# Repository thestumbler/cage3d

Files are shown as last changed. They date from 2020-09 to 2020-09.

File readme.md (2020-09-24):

# A Novel 3D Printer Enclosure

## Overview

This is an enclosure, or cage, for my 3D printer which I designed with
an eye towards not burning down the house.  I make no claim that it
meets any real fire-proofing codes, but I tried to select material which
wasn't going to burst into flames easily.

The target 3D printer is an Ender 5 Pro.  I suspect the dimensions of
this enclosure would work with several different printers.  If you
simply want to change the size, that is easy to do in the OpenSCAD file.
If you want to change the design, as in different number and kinds of
doors, you'll need more than a passing familiarity with OpenSCAD.

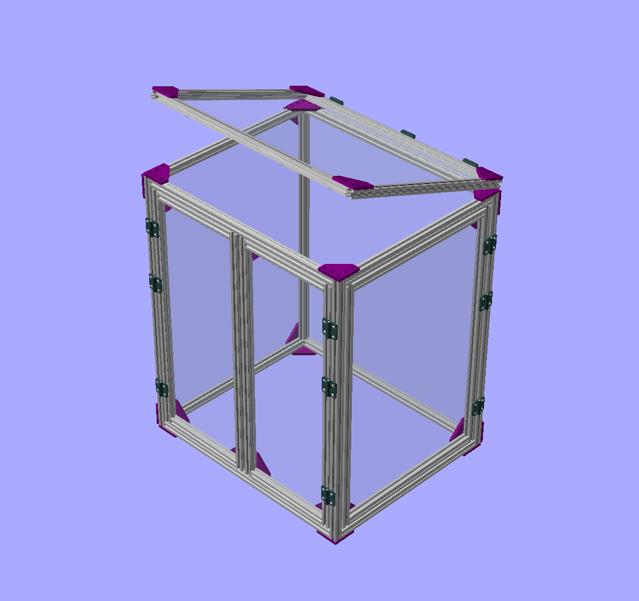
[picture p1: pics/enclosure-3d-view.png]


## Background

I've been curious for some time about 3D printers, but never took the
plunge until the virus hit.  Back in March, a friend of mine pointed 
out that he was making minuature people, cars, and buildings for his 
HO-gauge model railroad layout using a $300 printer from China.  
I knew the time had come.  His model was the Ender 3, but I splurged and
got the Ender 5 Pro.  

Shortly after receiving my new printer, another friend told me I needed
an enclosure, advice that I kept putting off until I realized he was
right.  After doing a little research, I wasn't really impressed with
any of the off-the-shelf solutions.  Having an enclosure that was not
flammable seemed to be desirable, but many of the popular ones weren't.  

I found a [discussion on reddit](https://www.reddit.com/r/3Dprinting/comments/6cn21j/has_anyone_built_a_fire_retardant_enclosure_for)
regarding fire-resistant boards which sounded promising. But I wasn't
readily able to find any cheaply here in South Korea.  I saw some people
were using plexiglass, but that's just plastic and would burn.
Then suddenly I realized that I could use tempered glass.
But I imagined the complex 3D pieces that would join panes of glass
together at the corners forming an enclosure, I became discouraged.  
Such a scheme would also need to accomodate doors, panels, mounting 
points for accessories, and I was about to abandon the idea.

Then I had another idea - use the same type of aluminum extrusions 
that comprised the 3D printer itself as frames for a glass enclosure.
This appeared to solve all my objections of custom joinery, and it
seemed to me, an electronics engineers, as a doable solution with
low-risk of failure.  But simple as it seemed, I was concerned about
building something like this without a metal working shop.

A bit of an aside, South Koreans are not really into the DIY scene.
Finding supplies that would be trivial to get in the US can be
challenging, if not impossible here.  In addition, without a workshop
here, extensive cutting, drilling, etc., is a non-starter.  To my
surprise, I was quickly able to find what I needed online, from
suppliers who did custom orders.  There are shops selling aluminum 2020
extrusions cut to custom lengths.  I also found a place that would cut
sheets of tempered glass to custom sizes, chamfers, and radii on
request.  With these newly-found resources at my fingertips, I was
encouraged to proceed.  

## See also:

* [Assembly instructions](assembly.md) guide on assembling the cage
* [Installation notes ](install.md) how to install the code, too basic
* [Gallery of pictures](gallery.md) an index into the pictures directory with some organization
* [Vendors used](vendors.md) list of vendors and links, useless unless you live in South Korea
* [Build log](build-log.md)
* [Design details](design.md)
* Datasheets directory (needs a few more datasheets)

## Design files:

* `cage.scad` OpenSCAD file
* `cage-bom.xlsx` BOM listing
  - `cage-bom-*.txt` intermediate bom text files generated by OpenSCAD
* `cage-panel.dwg` (also DXF and PDF files) drawing for basic panel

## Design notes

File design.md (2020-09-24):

# 3D Printer Enclosure Design Details

## Basic Construction

The basic building block of the enclosure, or cage, is a frame
made of standard 2020 aluminum profile extrusion.  The inside
grooves of these frames are used to hold a tempered glass panel.
The depth of the groove is 6mm, and I specified the glass panels 
to engage 5mm into the groove for a snug fit (see gasketing below).

One advantage of using 2020 extrusions is that accessories can easily be
mounted, such as a Raspi4 running Octoprint, LED light strips, etc.
My initial perception was that these profiles are reasonably cheap for
their functionality, but the key factor was they were easy for me obtain
in pre-cut lengths.

### Enclosure Size and Doors

The first step is to choose the size of the enclosure or cage.
Measuring my Ender 5 Pro printer, I decided on the following:

* 600 mm width, gives enough room for the filament spool
* 500 mm depth
* 700 mm height, should clear the filament feed tube

These dimensions are the outside dimensions in width and depth.
After wrapping up all the documentation, I realized the height was
actually 730 mm, slightly over one extusion width higher than the
"basic" dimension. This sneaked into the design as I was puzzling with
how to arrange all the doors, their frames, and the corners without
blocking the glass groove.  Somehow the top door ended up sitting atop
the whole cage, rather than recessed into the specified envelope.
In hindsight, this could probably be fixed, but at the time I was so
frustrated, I was just happy to get something that worked.

Three doors are included:

* Divided front doors to access the printing stage
* Side door to access to the filament reel and feeder
* Top door opens like a top-loader washing machine

## Joinery

I found several metal joints for 2D and 3D corners, some were really
cool cast aluminum joints.  But these usually interfered with the groove
for the glass.  But eventually I went with flat triangular corner plate.
I bought these, but they could be printed on your 3D printer.
User `Mighty Nozzle` has a library which includes these.

These plates use a lot of bolts, five per corner.  I'm not sure if they
are really necessary or not.  I erred on the side of caution, especially
after I calculated the weight of all this tempered glass.

## Hinges / Doors

Hinges were another concern, but I found some which were suitable sized
and spaced to make the doors. The ones I selected give a 5mm gap between
the frame and the doors.  I think that is a little large, but in the
beginning, I wasn't sure what kind of length tolerances I would get on
the extrusions.  I decided to keep a 5 mm door gap, and also to make all
dimensions a multiple of 5 mm.

Note, if you are using 3D printed corners, the gap could be an issue on
the top door.  In that case, the top door hinges would need to have a
larger gap, or else print those corners thinner. I found some hinges
that gave a 10 mm gap, which I think would be plenty.

## Meta

The design was visualized in OpenSCAD.  This is great for playing around
and experimenting with different options.  But it isn't so great for the
final documentation of the design.  The file becomes cluttered with all
kinds of visual aids and tests, like 

* XYZ axes
* grid lines (regular and isometric)
* overall dimension lines
* individual panel extrusion sizes (for assy help)
* animation to show exploded view, with lines
* poor-man's BOM generation `echo` statements

I tried comment it, but there will surely be questions, even from
myself.  Random remarks.

I wanted to make an isometric assembly drawing, and I will never take
this approach again.  What I did was draw isometric grid lines in
OpenSCAD, then export a PNG file, made the background transparent with
Gimp, and imported it into AutoCAD.  Whereupon I reconstructed the grids
on separate layers which I used as snap points to the Find Number
callouts.  I then replaced the AudoCAD image with another one without
isometric grids, and VOILA.  What a PITA.  It's time to take up bite the
bullet on Fusion 360.

Check out the script `mkbom.sh` which runs OpenSCAD from the command
line, and collects and sorts the output to create a really simple BOM.
The output isn't a perfect BOM, but it is a great starting point
containing the basic information needed on the "real" BOM.  Things like:

* X & Y dimensions of the finished panels
* length of individual extrusions
* X & Y dimensions of the glass panels
* perimeter of the glass panels (for gasket length)
* X + Y (sum) of glass panels (this is how the supplier prices them)
* weight of the extrusions and glass panels

## BOM and Rollups

TBD

## Tools

I tried to use open-source tools in the development of this project, but
failed, sort of.  OpenSCAD is open source, as is Gimp (see above).  I
used Excel for the BOM, but I could have used gnumeric or libreoffice.
The biggest break with open source tools is AutoCAD, or more precisely,
DraftSight.  I've been using them for years, when I lost my two ancient
AutoCAD license during a move.  Until recently, DraftSight was free.
But they have started charging an annual license fee, about $100 for the
entry level.  It is really hard to relearn 25 years of muscle memory of
the AutoCAD commands. And I so rarely use mechanical CAD tools, it's
tough to invest the time and/or money to learn a new tool.  I'm still
undecided on this one.  

The design files, however, should be usable in other open source tools.
The xlsx spreadsheets can be imported in other spreadsheet programs, and
I exported an ASCII DXF file from DraftSight.

## Metric

Because I live in South Korea, the overwhelming majority of material I
can get here is measured in Metric units. This design is dimensioned
accordingly.  Furthermore, fasteners are all metric threads.  I should
be a simple task to tweak the design to the equivalent Imperial units.
For example 

* M3 ~~ #4-40
* M3.5 ~~ #6-32 (oddball size?)
* M4 ~~ #8-32
* M5 ~~ #10-32 or #10-24

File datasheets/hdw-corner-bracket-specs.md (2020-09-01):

# Corner Bracket Specs

These limited specifications are take from this [AliExpress page](https://www.aliexpress.com/item/33007779262.html).

* Application: 
  - Build CNC routers
  - 3D printers
  - CNC laser cutters
  - CNC plasma cutters
  - robotics projects
  - 3D carvers
  - machine guards
  - workstations, etc.
* Compatible with: 
  - 2020 Series
  - Misumi Series
  - Openbuilds V-Slot
  - Openbuilds C-Beam
  - and other standard v-slot/L-slot 20mm aluminum extrusions
* For 2020 the size is 60mm x 60mm x 4mm
* Recommend to use M5 x10mm screw and M5 T nut
* Material: Aluminum
* Colour: Silver
* Aperture: M5
* Holes Spaced：20mm / 0.79 inch
* Thickness：4mm / 0.16 inch
* Dimensions: 60mm x 60mm /2.36 x 2.36 inch

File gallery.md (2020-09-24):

# Gallery of pictures

Just a markdown file to access the images, and a place to put comments
about the photos when appropriate.

## What Am I Making?

#### Enclosure (cage) for an Ender 5 Pro 3D printer
Enclosure (cage) for an Ender 5 Pro 3D printer

## First Test

Before jumping into the deep waters, I made a test panel first.
This is the smallest panel in the design, one of the front doors.

#### Test panel, front door
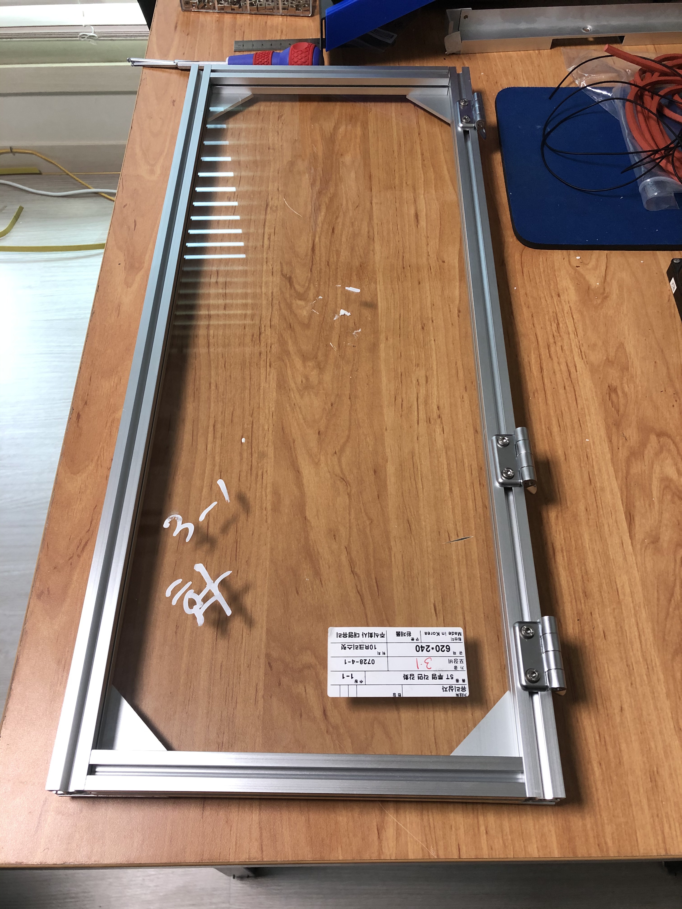
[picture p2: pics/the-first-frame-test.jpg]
Test panel, front door


## Detailed views

#### Frame corner detail
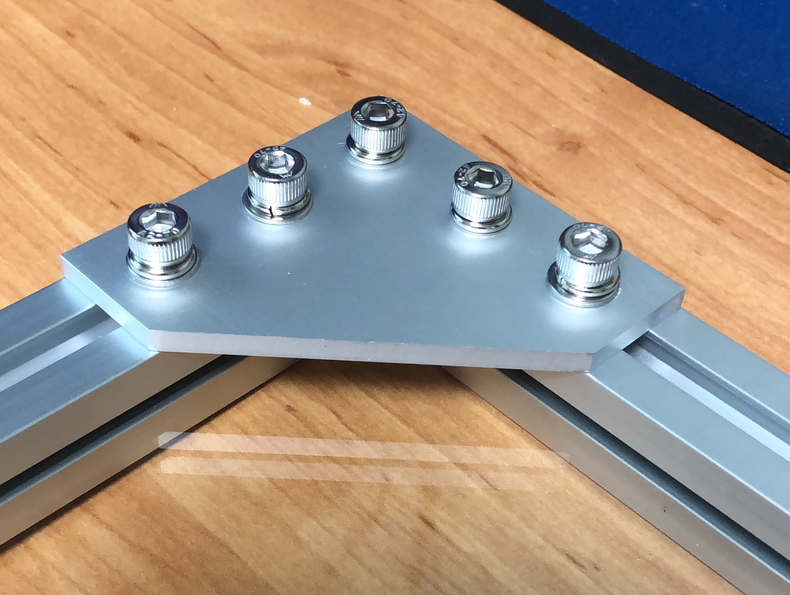
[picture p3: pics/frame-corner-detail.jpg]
Detail view of assembled frame corner


#### Frame hinge detail
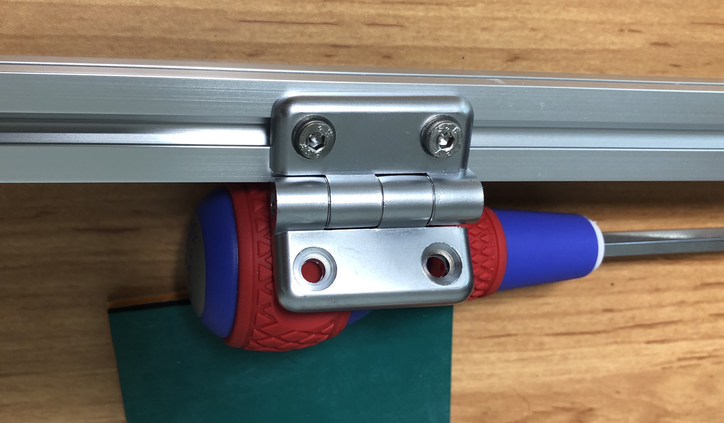
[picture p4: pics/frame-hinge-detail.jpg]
Detail view of hinge installation


## I Hate Rubber Gaskets

#### The pesky rubber gasket, my plan didn't go well
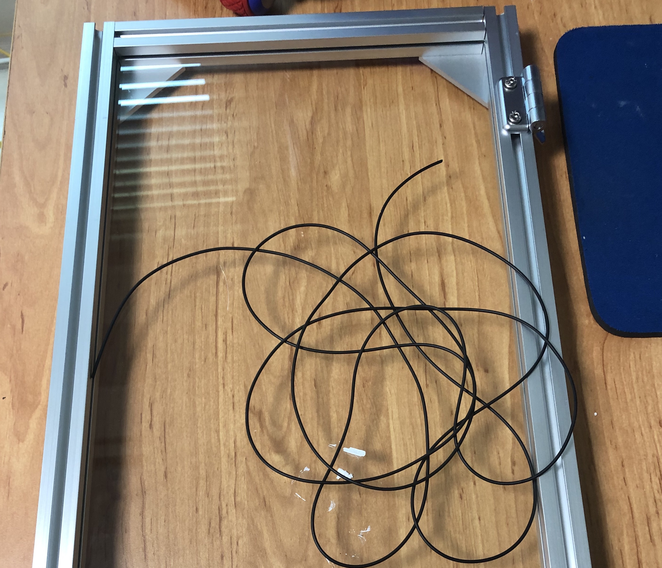
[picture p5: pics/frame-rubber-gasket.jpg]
The pesky rubber gasket


#### It looks good on paper
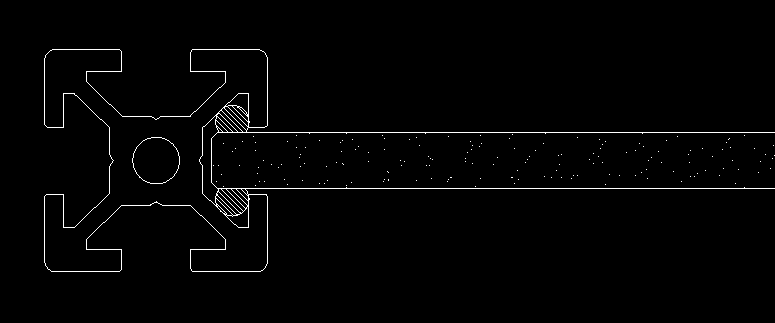
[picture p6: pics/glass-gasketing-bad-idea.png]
It looks good on paper


## Arriving Parts, Glass Panels

#### Glass panels arrived, surprisingly they didn't break
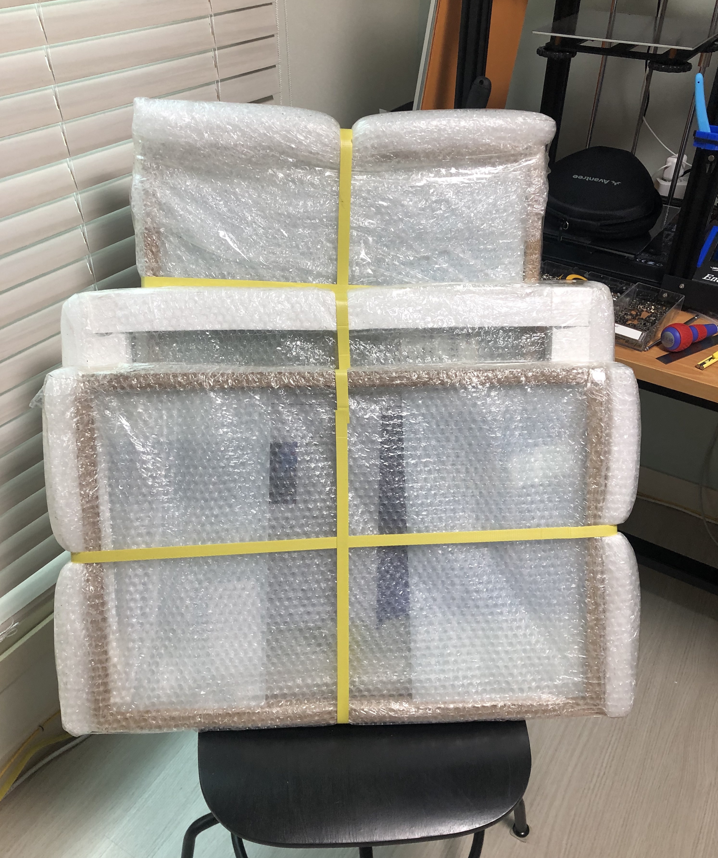
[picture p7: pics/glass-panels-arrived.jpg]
Glass panels arrived


#### Glass panels inspection, measure and check
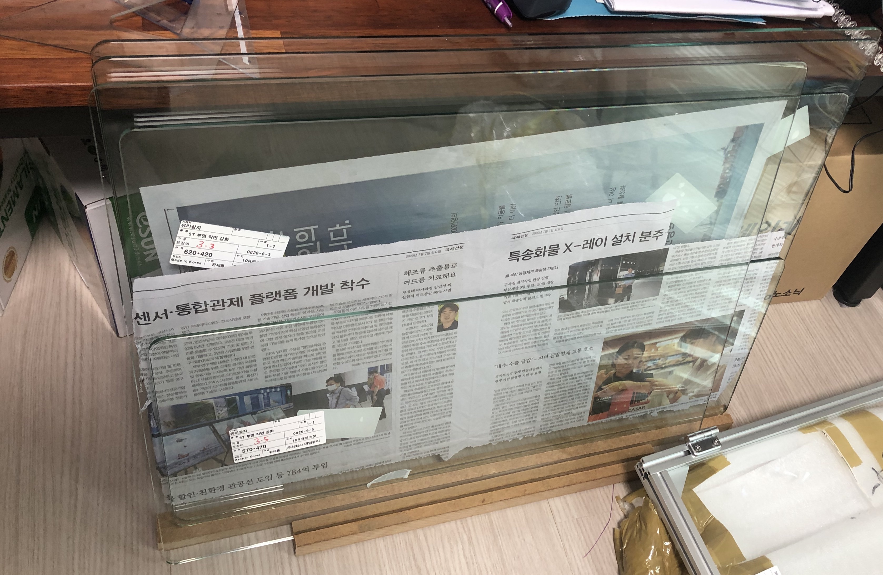
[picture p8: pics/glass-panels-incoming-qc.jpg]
Glass panels inspection


#### Separate our recycling required here in South Korea
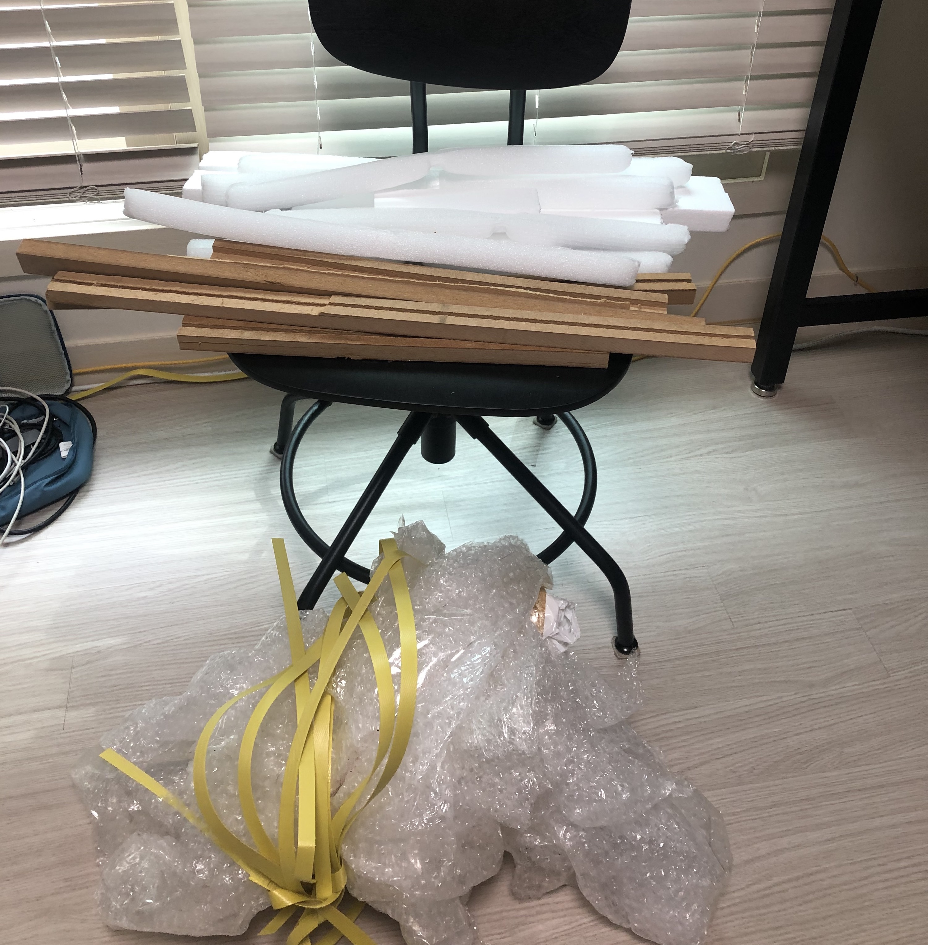
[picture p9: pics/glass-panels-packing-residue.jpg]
Glass panels packaging trash


## Arriving Parts, Extrusions

#### Aluminum profiles arrived
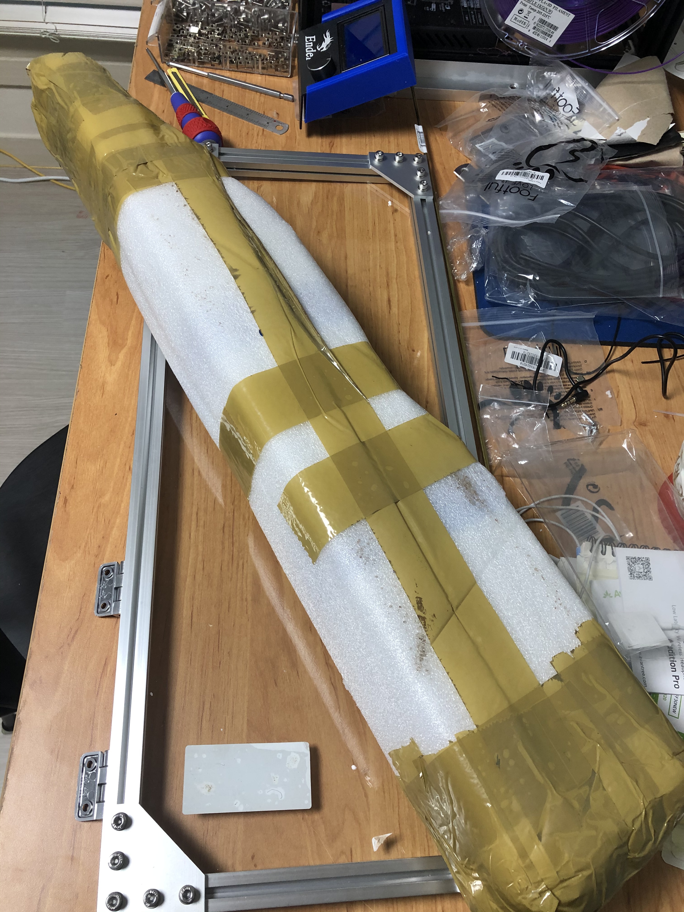
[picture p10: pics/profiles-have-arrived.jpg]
Aluminum profiles arrived


#### Aluminum profiles unpacked
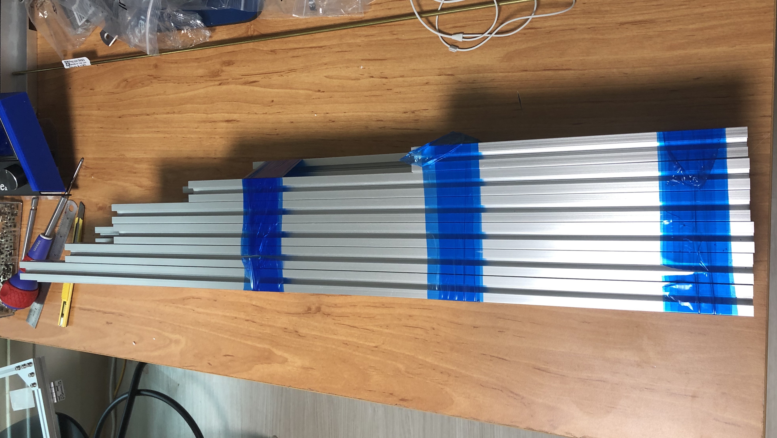
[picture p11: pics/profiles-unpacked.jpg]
Aluminum profiles unpacked


#### Aluminum profiles inspection.1 OOPS
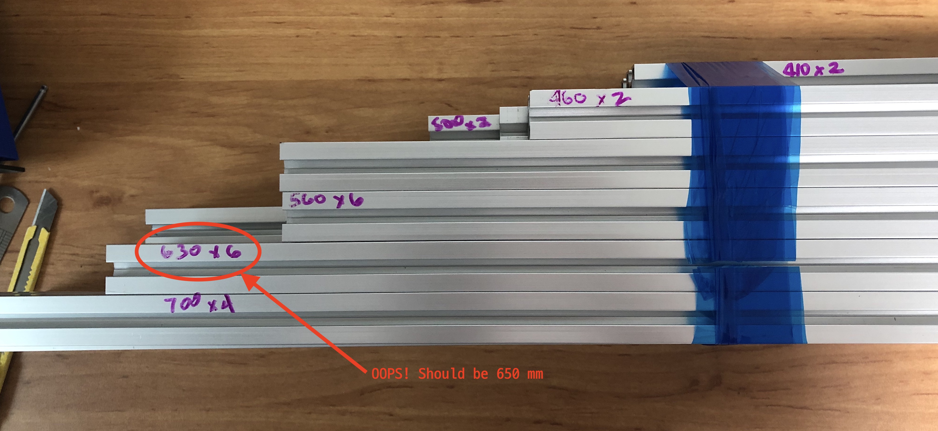
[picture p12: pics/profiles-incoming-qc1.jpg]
Aluminum profiles inspection.1 OOPS


#### Aluminum profiles inspection.2
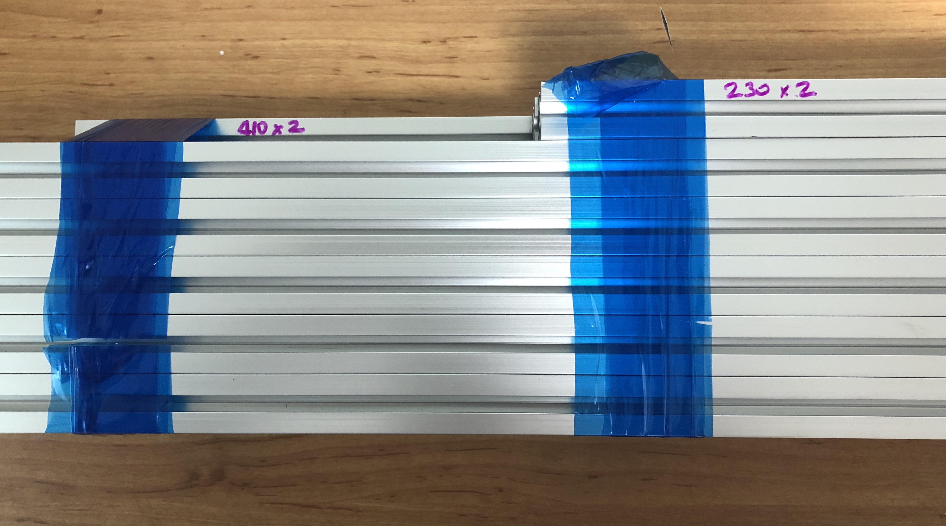
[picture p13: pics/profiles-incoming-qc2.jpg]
Aluminum profiles inspection.2


## Assembly Details

#### Completed Enclosure, Worms-eye view
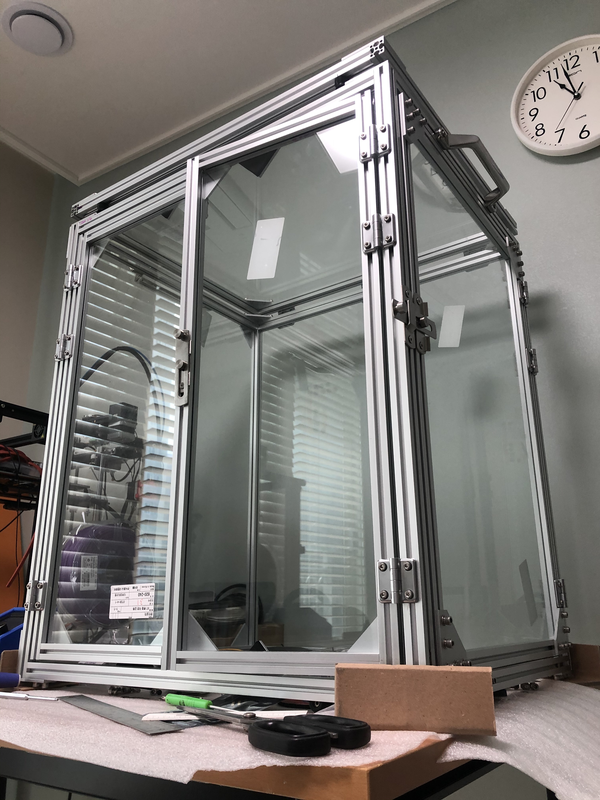
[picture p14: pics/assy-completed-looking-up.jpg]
Completed Enclosure, Worms-eye view


#### Almost There
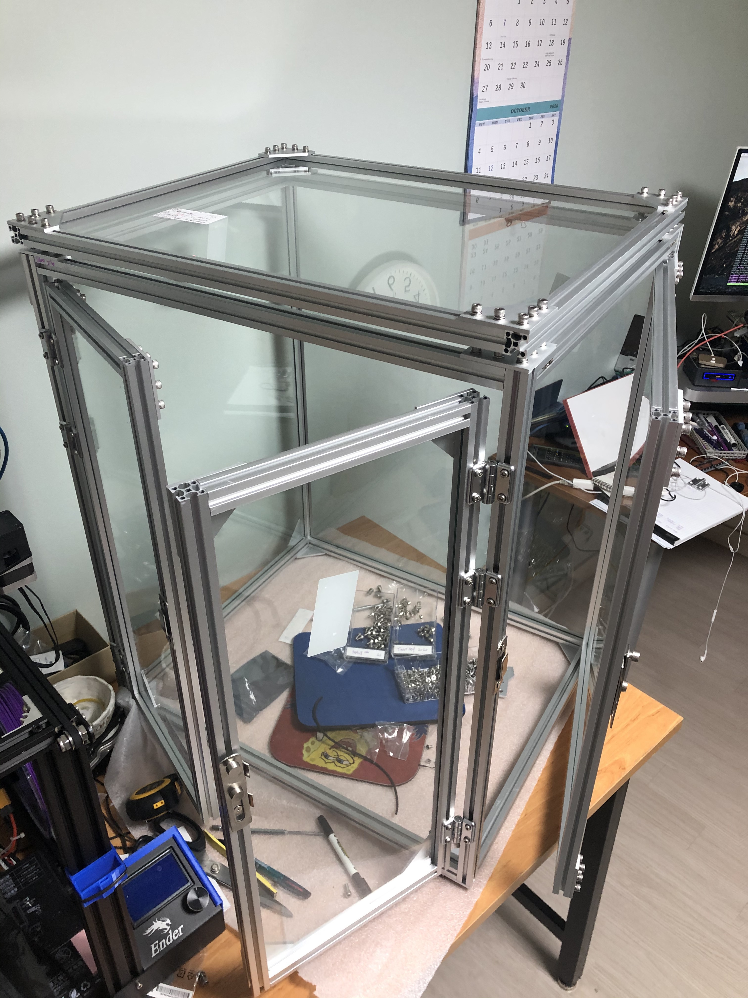
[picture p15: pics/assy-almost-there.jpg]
Almost There


#### Corner can slide
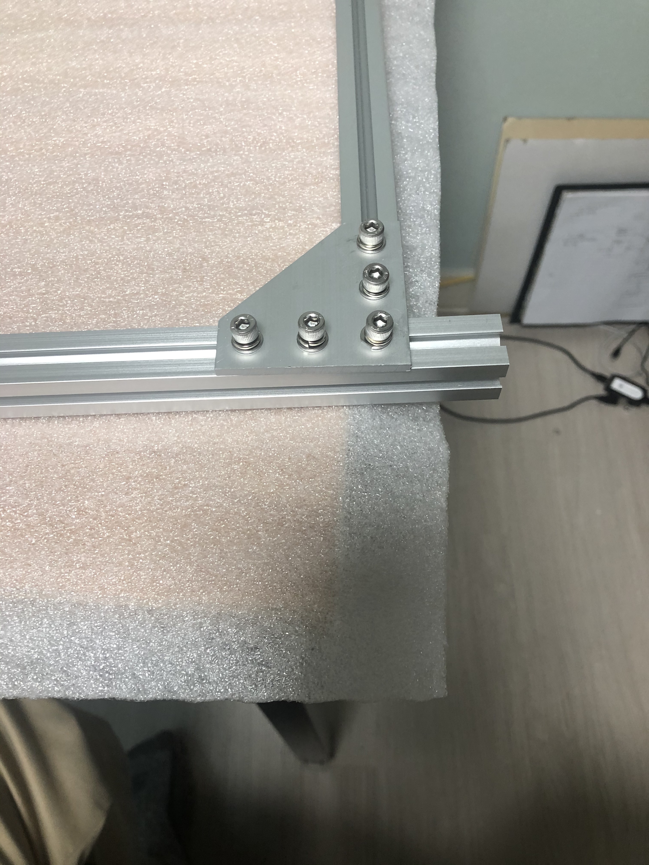
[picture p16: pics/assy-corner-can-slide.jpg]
Corner can slide


#### Completed corner
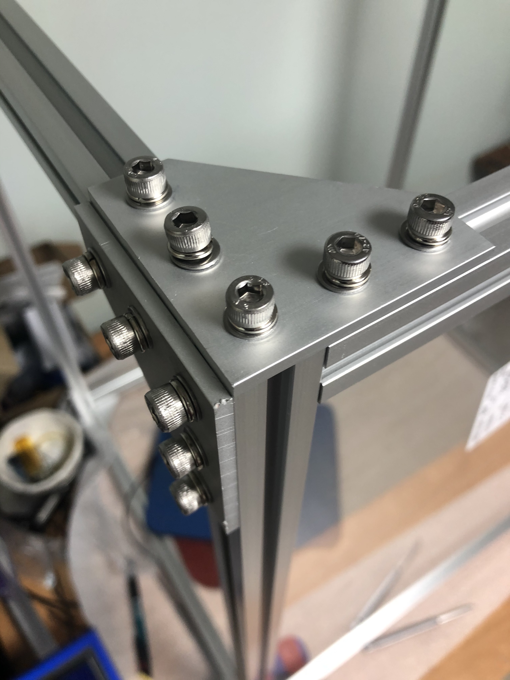
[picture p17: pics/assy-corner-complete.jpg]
Completed corner


#### Better not forget the square nuts
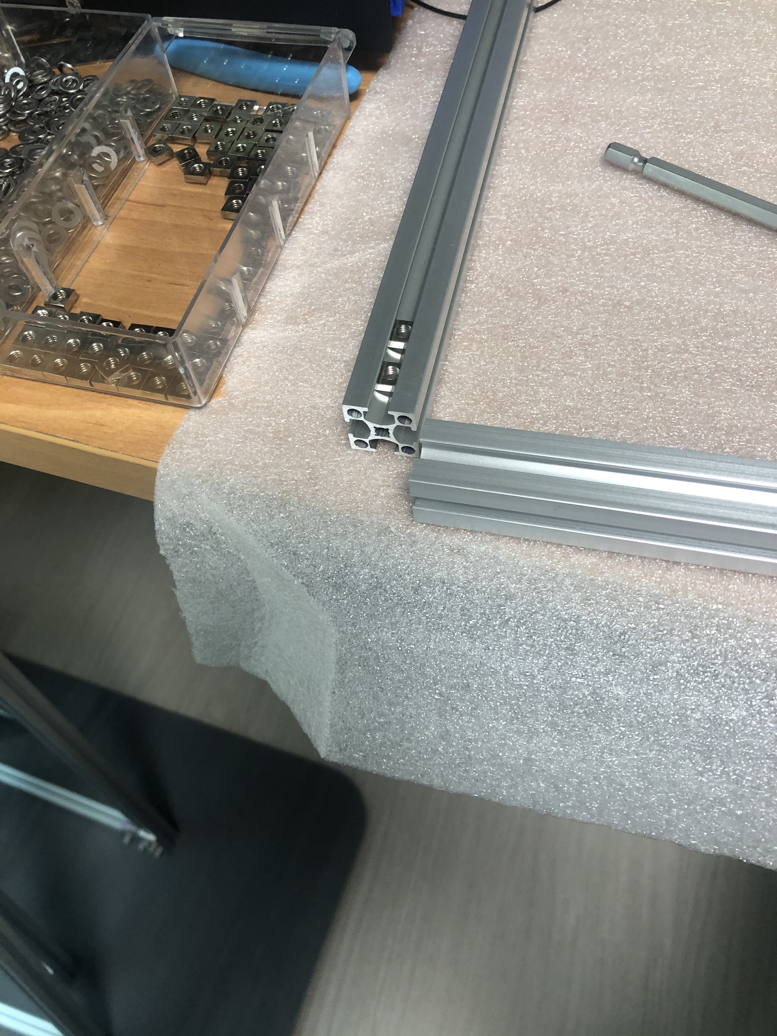
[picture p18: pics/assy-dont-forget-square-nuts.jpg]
Better not forget the square nuts


#### Too many square nuts
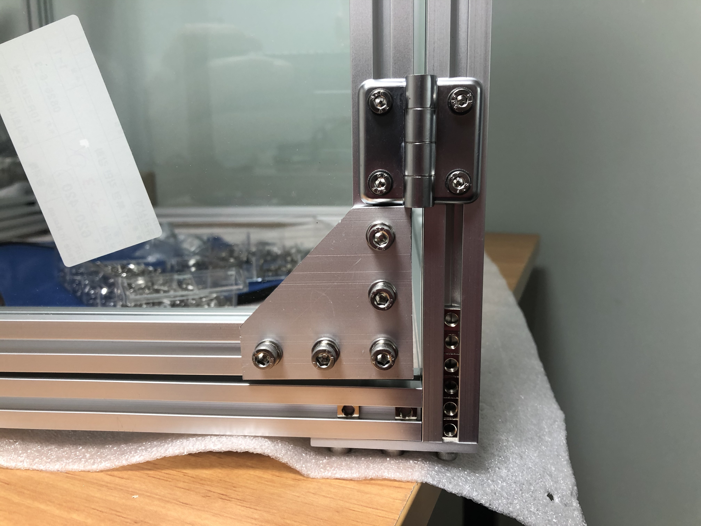
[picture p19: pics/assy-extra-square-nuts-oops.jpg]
Too many square nuts


#### Door latch detail
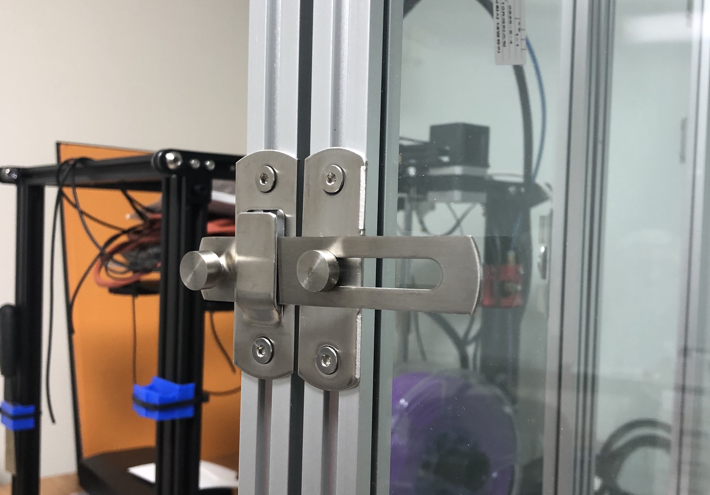
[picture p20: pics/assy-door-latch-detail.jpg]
Door latch detail


#### Door stop detail
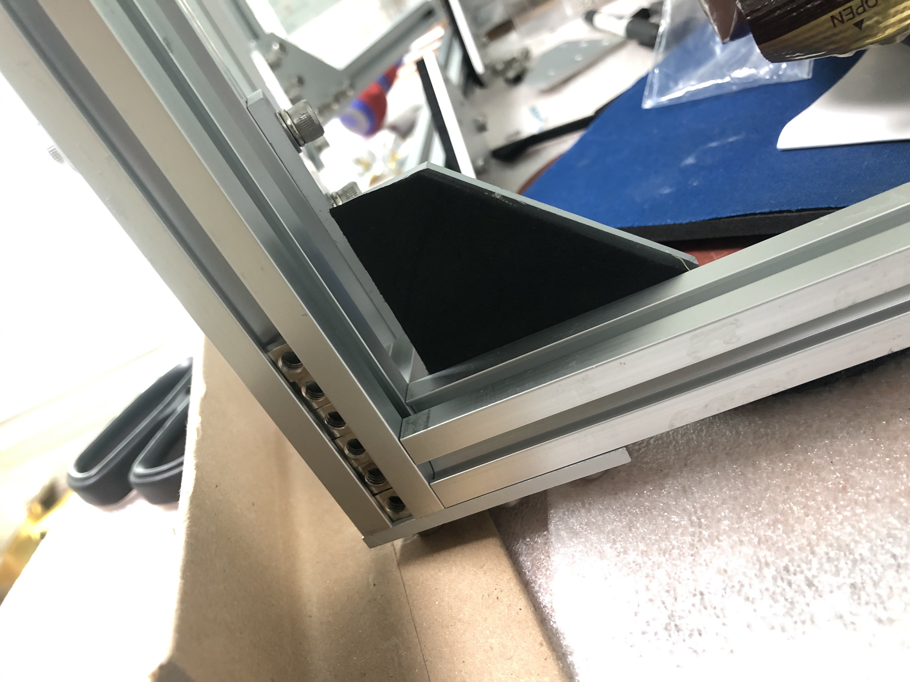
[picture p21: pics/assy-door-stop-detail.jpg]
Door stop detail


#### Example corner before installation
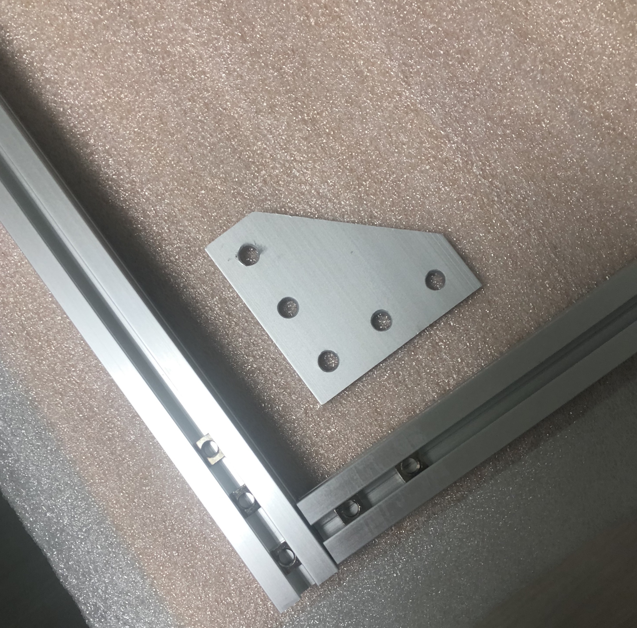
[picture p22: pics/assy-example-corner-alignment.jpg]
Example corner before installation


#### Front door stop detail
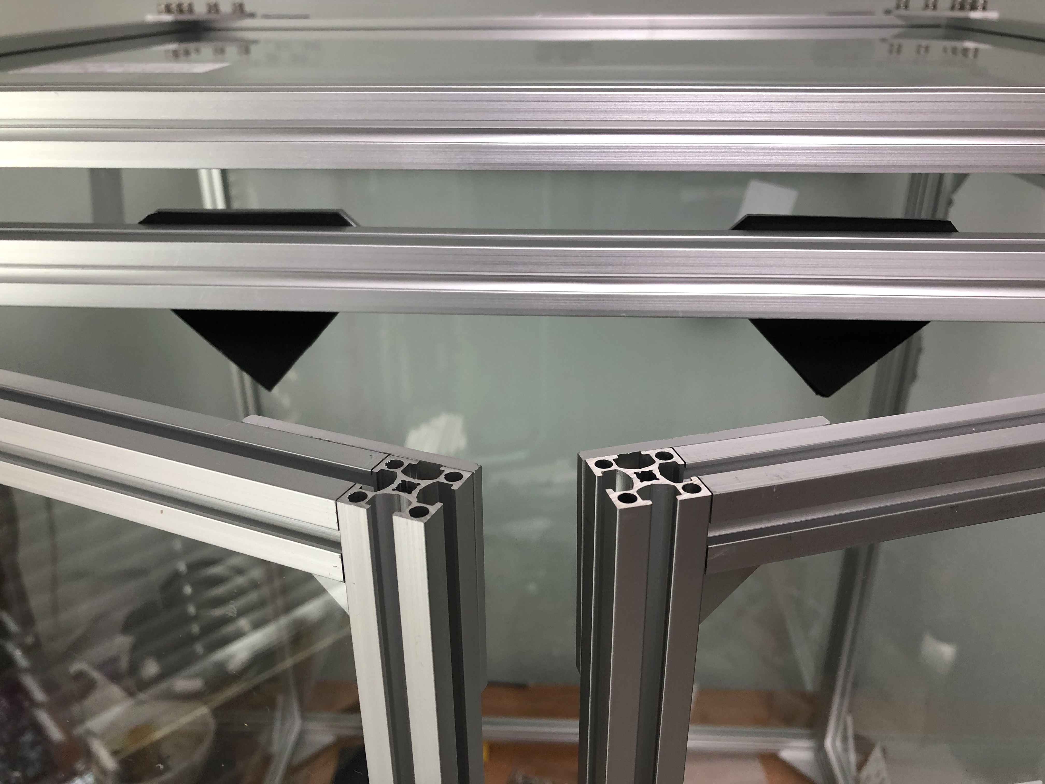
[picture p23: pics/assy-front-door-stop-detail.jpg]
Front door stop detail


#### Hinge detail
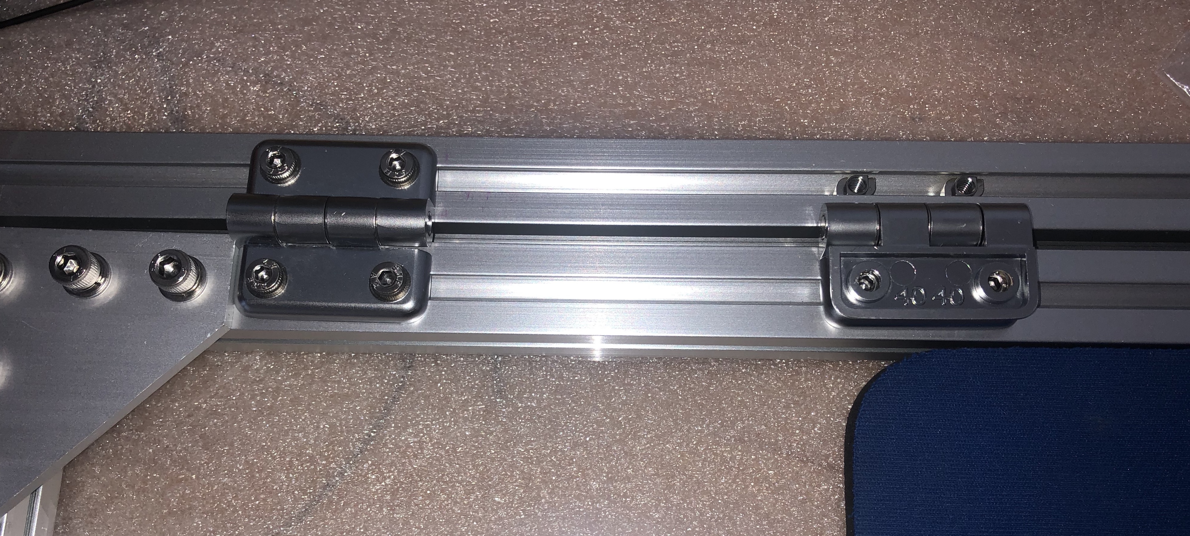
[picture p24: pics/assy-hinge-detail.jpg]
Hinge detail


#### Making door stops
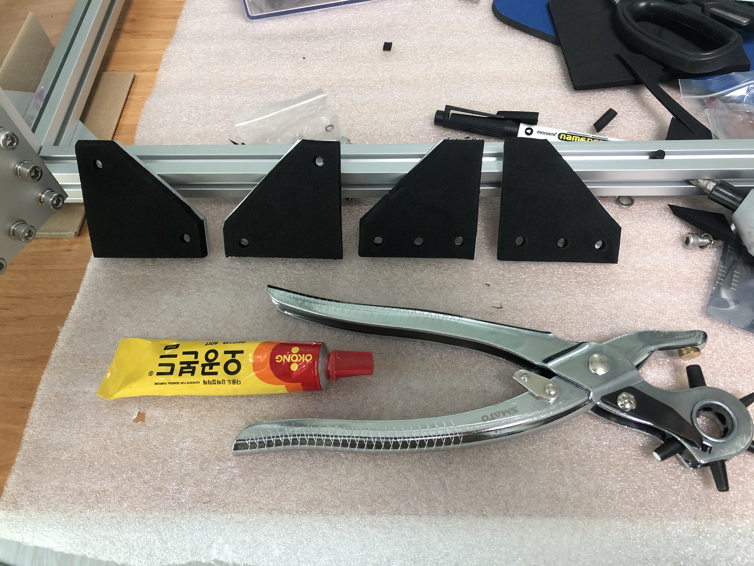
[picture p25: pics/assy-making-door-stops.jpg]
Making door stops


#### Rear hinge detail
Rear hinge detail

#### Tapping the end holes
Tapping the end holes

#### Tapping the end holes
Tapping the end holes

#### Tapping the end holes
Tapping the end holes

#### Cube assembled, time to tap the holes
Cube assembled, time to tap the holes

#### Tee-nut, right and wrong
Tee-nut, right and wrong

#### Top door bumpers, left
Top door bumpers, left

#### Top door bumpers, right
Top door bumpers, right

## Candidate cast aluminum corners

I passed on these despite them being really cool

#### cast corner 2D, internal style
cast corner 2D, internal style

#### cast corner 2D, external style
cast corner 2D, external style

#### cast corner 3D, internal style
cast corner 3D, internal style

## Misc stuff

#### Assembly hardwware
Assembly hardwware

#### Hex nut dimensions
Hex nut dimensions

#### Glass panels assembled
Glass panels assembled

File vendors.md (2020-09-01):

# Vendors used in this project

This list will be almost useless unless you live in South Korea.
I primarily made it for my own reference, but the links might give 
someone hints for locating similar items in their region.

* Aluminum 2020 extrusions
  - http://global.gmarket.co.kr/item?goodsCode=1688992222
* Tempered Glass panels
  - http://global.gmarket.co.kr/item?goodsCode=1344564398
* Aluminum Corners:
  - https://www.aliexpress.com/item/33007779262.html
* Hinges, HC4040 matte finish, cast
  - http://global.gmarket.co.kr/item?goodsCode=802764159
* Rubber seal candidates:
  * 5mm square, pink silicon foam, 25-30 shore A
    - http://global.gmarket.co.kr/item?goodsCode=1344564398
  * Black NBR rubber, various diameters, 70 shore A
    - http://global.gmarket.co.kr/item?goodsCode=1461701921
* Latches
  - https://www.coupang.com/vp/products/295612249
* Hardware (machine screws, bolts, washers, etc.)
  - Samdi Mall
  - Youngwon Tool

### CH77 Special Rubber Co.

```
CH77 Special Rubber Co.
http://ch77-7.com
197 Gurojungang-ro, 
Guro-dong, Guro-gu, Seoul
tel: 02-6232-8700

씨에이치특수고무
```

### Myeongga Hardware Co.

```
Myeongga Hardware Co.
24, Sinchon-ro, Dongnam-gu, 
Cheonan-si, Chungcheongnam-do
web: http://www.mg9000.com
web: http://www.mgjs.co.kr

충청남도 천안시 신방동 784-1
```

### Dae Myoung Glass Company

```
Dae Myoung Glass Company
web: http://dm-glass.co.kr
```

### Dongwon Tech / 09-Play

```
Dongwon Tech / 09-Play
Bldg 16, Suite 113, Siheung Distribution Center
97, Siheung-daero, Geumcheon-gu, Seoul
tel:02-6264-8992
email: dwcnt@naver.com
web: http://www.09play.co.kr

동원테크
서울특별시 금천구 시흥대로 97
시흥유통상가) 16동 113호
```

### Youngwon Tool

```
Youngwon Tool
Korea Iso Co Building
152, Sandong-ro, Eumbong-myeon
Asan-si, Chungcheongnam-do
tel: 041-557-1516
email: yw6987@daum.net
web: http://01mall.co.kr

충청남도 아산시 음봉면 산동로 152
```

### Samdi Mall

```
Samdi Mall
Dongyang Bldg, 2nd floor
301 Bucheon-ro, 
Bucheon-si, Gyeonggi-do
tel: 032-674-7037
email: samdimall@gmail.com
web: http://www.samdimall.com

경기도 부천시 부천로 301 동양빌딩 2층
```

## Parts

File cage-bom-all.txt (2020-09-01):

BOM	panel.side.left	500	700	460	700
BOM	ex2020	460	0.1748
BOM	ex2020	460	0.1748
BOM	ex2020	700	0.266
BOM	ex2020	700	0.266
BOM	corner	5
BOM	corner	5
BOM	corner	5
BOM	corner	5
BOM	glass.side.left	470	670	0.3149	2280	3.93625
BOM	panel.side.right.noglass	500	700	460	700
BOM	ex2020	460	0.1748
BOM	ex2020	460	0.1748
BOM	ex2020	700	0.266
BOM	ex2020	700	0.266
BOM	ex2020.standalone	560	0.2128
BOM	ex2020.standalone	560	0.2128
BOM	corner.standalone	5
BOM	corner.standalone	5
BOM	corner.standalone	5
BOM	corner.standalone	5
BOM	ex2020.standalone	560	0.2128
BOM	ex2020.standalone	560	0.2128
BOM	corner.standalone	5
BOM	corner.standalone	5
BOM	corner.standalone	5
BOM	corner.standalone	5
BOM	glass.back.standalone	570	670	0.3819	2480	4.77375
BOM	corner.standalone	5
BOM	corner.standalone	5
BOM	corner.standalone	5
BOM	corner.standalone	5
BOM	panel.side.door	450	650	410	650
BOM	ex2020	410	0.1558
BOM	ex2020	410	0.1558
BOM	ex2020	650	0.247
BOM	ex2020	650	0.247
BOM	corner	5
BOM	corner	5
BOM	corner	5
BOM	corner	5
BOM	hinge	4
BOM	hinge	4
BOM	hinge	4
BOM	glass.side.door	420	620	0.2604	2080	3.255
BOM	panel.front.door.left	270	650	230	650
BOM	ex2020	230	0.0874
BOM	ex2020	230	0.0874
BOM	ex2020	650	0.247
BOM	ex2020	650	0.247
BOM	corner	5
BOM	corner	5
BOM	corner	5
BOM	corner	5
BOM	hinge	4
BOM	hinge	4
BOM	hinge	4
BOM	glass.front.door.left	240	620	0.1488	1720	1.86
BOM	panel.front.door.right	270	650	230	650
BOM	ex2020	230	0.0874
BOM	ex2020	230	0.0874
BOM	ex2020	650	0.247
BOM	ex2020	650	0.247
BOM	corner	5
BOM	corner	5
BOM	corner	5
BOM	corner	5
BOM	hinge	4
BOM	hinge	4
BOM	hinge	4
BOM	glass.front.door.right	240	620	0.1488	1720	1.86
BOM	panel.top.door	600	500	560	500
BOM	ex2020	560	0.2128
BOM	ex2020	560	0.2128
BOM	ex2020	500	0.19
BOM	ex2020	500	0.19
BOM	corner	5
BOM	corner	5
BOM	corner	5
BOM	corner	5
BOM	glass.top.door	570	470	0.2679	2080	3.34875
BOM	hinge	4
BOM	hinge	4
BOM	hinge	4

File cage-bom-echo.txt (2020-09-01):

ECHO: [0, 0.125, 0.25, 0.375, 0.5, 0.625, 0.75, 0.875, 1]
ECHO: "BOM	panel.side.left	500	700	460	700"
ECHO: "BOM	ex2020	460	0.1748"
ECHO: "BOM	ex2020	460	0.1748"
ECHO: "BOM	ex2020	700	0.266"
ECHO: "BOM	ex2020	700	0.266"
ECHO: "BOM	corner	5"
ECHO: "BOM	corner	5"
ECHO: "BOM	corner	5"
ECHO: "BOM	corner	5"
ECHO: "BOM	glass.side.left	470	670	0.3149	2280	3.93625"
ECHO: "BOM	panel.side.right.noglass	500	700	460	700"
ECHO: "BOM	ex2020	460	0.1748"
ECHO: "BOM	ex2020	460	0.1748"
ECHO: "BOM	ex2020	700	0.266"
ECHO: "BOM	ex2020	700	0.266"
ECHO: "BOM	ex2020.standalone	560	0.2128"
ECHO: "BOM	ex2020.standalone	560	0.2128"
ECHO: "BOM	corner.standalone	5"
ECHO: "BOM	corner.standalone	5"
ECHO: "BOM	corner.standalone	5"
ECHO: "BOM	corner.standalone	5"
ECHO: "BOM	ex2020.standalone	560	0.2128"
ECHO: "BOM	ex2020.standalone	560	0.2128"
ECHO: "BOM	corner.standalone	5"
ECHO: "BOM	corner.standalone	5"
ECHO: "BOM	corner.standalone	5"
ECHO: "BOM	corner.standalone	5"
ECHO: "BOM	glass.back.standalone	570	670	0.3819	2480	4.77375"
ECHO: "BOM	corner.standalone	5"
ECHO: "BOM	corner.standalone	5"
ECHO: "BOM	corner.standalone	5"
ECHO: "BOM	corner.standalone	5"
ECHO: "BOM	panel.side.door	450	650	410	650"
ECHO: "BOM	ex2020	410	0.1558"
ECHO: "BOM	ex2020	410	0.1558"
ECHO: "BOM	ex2020	650	0.247"
ECHO: "BOM	ex2020	650	0.247"
ECHO: "BOM	corner	5"
ECHO: "BOM	corner	5"
ECHO: "BOM	corner	5"
ECHO: "BOM	corner	5"
ECHO: "BOM	hinge	4"
ECHO: "BOM	hinge	4"
ECHO: "BOM	hinge	4"
ECHO: "BOM	glass.side.door	420	620	0.2604	2080	3.255"
ECHO: "BOM	panel.front.door.left	270	650	230	650"
ECHO: "BOM	ex2020	230	0.0874"
ECHO: "BOM	ex2020	230	0.0874"
ECHO: "BOM	ex2020	650	0.247"
ECHO: "BOM	ex2020	650	0.247"
ECHO: "BOM	corner	5"
ECHO: "BOM	corner	5"
ECHO: "BOM	corner	5"
ECHO: "BOM	corner	5"
ECHO: "BOM	hinge	4"
ECHO: "BOM	hinge	4"
ECHO: "BOM	hinge	4"
ECHO: "BOM	glass.front.door.left	240	620	0.1488	1720	1.86"
ECHO: "BOM	panel.front.door.right	270	650	230	650"
ECHO: "BOM	ex2020	230	0.0874"
ECHO: "BOM	ex2020	230	0.0874"
ECHO: "BOM	ex2020	650	0.247"
ECHO: "BOM	ex2020	650	0.247"
ECHO: "BOM	corner	5"
ECHO: "BOM	corner	5"
ECHO: "BOM	corner	5"
ECHO: "BOM	corner	5"
ECHO: "BOM	hinge	4"
ECHO: "BOM	hinge	4"
ECHO: "BOM	hinge	4"
ECHO: "BOM	glass.front.door.right	240	620	0.1488	1720	1.86"
ECHO: "BOM	panel.top.door	600	500	560	500"
ECHO: "BOM	ex2020	560	0.2128"
ECHO: "BOM	ex2020	560	0.2128"
ECHO: "BOM	ex2020	500	0.19"
ECHO: "BOM	ex2020	500	0.19"
ECHO: "BOM	corner	5"
ECHO: "BOM	corner	5"
ECHO: "BOM	corner	5"
ECHO: "BOM	corner	5"
ECHO: "BOM	glass.top.door	570	470	0.2679	2080	3.34875"
ECHO: "BOM	hinge	4"
ECHO: "BOM	hinge	4"
ECHO: "BOM	hinge	4"

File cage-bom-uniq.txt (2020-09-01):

  20 BOM	corner	5
  12 BOM	corner.standalone	5
   4 BOM	ex2020	230	0.0874
   2 BOM	ex2020	410	0.1558
   4 BOM	ex2020	460	0.1748
   2 BOM	ex2020	500	0.19
   2 BOM	ex2020	560	0.2128
   6 BOM	ex2020	650	0.247
   4 BOM	ex2020	700	0.266
   4 BOM	ex2020.standalone	560	0.2128
   1 BOM	glass.back.standalone	570	670	0.3819	2480	4.77375
   1 BOM	glass.front.door.left	240	620	0.1488	1720	1.86
   1 BOM	glass.front.door.right	240	620	0.1488	1720	1.86
   1 BOM	glass.side.door	420	620	0.2604	2080	3.255
   1 BOM	glass.side.left	470	670	0.3149	2280	3.93625
   1 BOM	glass.top.door	570	470	0.2679	2080	3.34875
  12 BOM	hinge	4
   1 BOM	panel.front.door.left	270	650	230	650
   1 BOM	panel.front.door.right	270	650	230	650
   1 BOM	panel.side.door	450	650	410	650
   1 BOM	panel.side.left	500	700	460	700
   1 BOM	panel.side.right.noglass	500	700	460	700
   1 BOM	panel.top.door	600	500	560	500

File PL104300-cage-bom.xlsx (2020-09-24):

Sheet: bom
TITLE |  | ENDER 5 PRO ENCLOSURE ASSY
DWG TYPE |  | ASSY, TOP LEVEL PARTS LIST
PART NO |  | PL104300
DESIGNER |  | CHRIS LOTT
COMPANY |  | THE STUMBLER
LOCATION |  | SACHEON, SOUTH KOREA
PAGE |  | 1 of 3
TOP-LEVEL ASSEMBLY PARTS LIST
F/N | Qty | Reference | COMM | Manufacturer | PartNo | Description | Remarks | Vendor | StockingNo
101 | 1 | FG.L | ASY | STUMBLER | 104320-700-500-FG | Panel, Frame w/Glass, 700 x 500 mm
102 | 1 | FX.R | ASY | STUMBLER | 104320-700-500-F | Panel, Frame no Glass, 700 x 500 mm
103 | 1 | PS.K | ASY | STUMBLER | 104320-600-700-G | Panel, Pseudo, Glass w/no Frame
104 | 1 | PS.T, PS.B | ASY | STUMBLER | 104320-000-600 | Panel, Pseudo, Frame
151 | 2 | DR.FL, DR.FR | ASY | STUMBLER | 104320-650-270-FG | Panel, Frame w/Glass, 650 x 270 mm
152 | 1 | DR.T | ASY | STUMBLER | 104320-500-600-FG | Panel, Frame w/Glass, 500 x 600 mm
153 | 1 | DR.R | ASY | STUMBLER | 104320-650-450-FG | Panel, Frame w/Glass, 650 x 450 mm
232 | 12 |  | HDW |  |  | Hinges |  | MYEONGGA
225 | 48 |  | HDW |  |  | Screw, MS, SHCS, SS, M4 x |  | SAMDI
226 | 48 |  | HDW |  |  | Nut, 2020 Tee-slot, SS, M4 |  | SAMDI
 | REFERENCE DESIGNATOR KEY:
 | FG | Frame Panel w/Glass
 | FX | Frame Panel w/Glass
 | PS | Pseudo panel
 | DR | Door
 | Suffix:
 | L | Left
 | R | Right
 | T | Top
 | B | Bottom
 | F | Front
 | K | bacK

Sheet: roll-down
TITLE |  | ENDER 5 PRO ENCLOSURE ASSY
DWG TYPE |  | ASSY, TOP LEVEL PARTS LIST
PART NO |  | PL104300
DESIGNER |  | CHRIS LOTT
COMPANY |  | THE STUMBLER
LOCATION |  | SACHEON, SOUTH KOREA
PAGE |  | 2 of 3
EXPLODED PARTS LIST, SORTED BY SUB-ASSEMBLY
F/N | Used-On | Qty | Reference | COMM | Description
207 | 101.1 | 2 | FG.L | MECH | Extrusion, 2020 AL, 700 mm
203 | 101.2 | 2 | FG.L | MECH | Extrusion, 2020 AL, 460 mm
215 | 101.3 | 1 | FG.L | CER | Glass, tempered, 670 x 470 x 5mm, R=10mm
211 | 101.4 | 2.28 | FG.L | RUB | Gasket Seal for 670 x 470 glass panel
231 | 101.5 | 4 | FG.L | HDW | Corners
222 | 101.6 | 20 | FG.L | HDW | Screw, MS, SHCS, SS, M5 x
223 | 101.7 | 20 | FG.L | HDW | Washer, Flat, SS, M5
224 | 101.8 | 20 | FG.L | HDW | Washer, Locking, Split-ring, SS, M5
221 | 101.9 | 20 | FG.L | HDW | Nut, Square, SS, 8x8x3mm, M5
207 | 102.1 | 2 | FX.R | MECH | Extrusion, 2020 AL, 700 mm
203 | 102.2 | 2 | FX.R | MECH | Extrusion, 2020 AL, 460 mm
231 | 102.3 | 4 | FX.R | HDW | Corners
222 | 102.4 | 20 | FX.R | HDW | Screw, MS, SHCS, SS, M5 x
223 | 102.5 | 20 | FX.R | HDW | Washer, Flat, SS, M5
224 | 102.6 | 20 | FX.R | HDW | Washer, Locking, Split-ring, SS, M5
221 | 102.7 | 20 | FX.R | HDW | Nut, Square, SS, 8x8x3mm, M5
215 | 103.1 | 1 | PS.K | CER | Glass, tempered, 670 x 570 x 5mm, R=10mm
211 | 103.2 | 2.48 | PS.K | RUB | Gasket Seal for 670 x 570 glass panel
231 | 103.3 | 4 | PS.K | HDW | Corners
222 | 103.4 | 20 | PS.K | HDW | Screw, MS, SHCS, SS, M5 x
223 | 103.5 | 20 | PS.K | HDW | Washer, Flat, SS, M5
224 | 103.6 | 20 | PS.K | HDW | Washer, Locking, Split-ring, SS, M5
221 | 103.7 | 20 | PS.K | HDW | Nut, Square, SS, 8x8x3mm, M5
205 | 104.11 | 2 | PS.T | MECH | Extrusion, 2020 AL, 560 mm
231 | 104.12 | 4 | PS.T | HDW | Corners
222 | 104.13 | 20 | PS.T | HDW | Screw, MS, SHCS, SS, M5 x
223 | 104.14 | 20 | PS.T | HDW | Washer, Flat, SS, M5
224 | 104.15 | 20 | PS.T | HDW | Washer, Locking, Split-ring, SS, M5
221 | 104.16 | 20 | PS.T | HDW | Nut, Square, SS, 8x8x3mm, M5
205 | 104.21 | 2 | PS.B | MECH | Extrusion, 2020 AL, 560 mm
231 | 104.22 | 4 | PS.B | HDW | Corners
222 | 104.23 | 20 | PS.B | HDW | Screw, MS, SHCS, SS, M5 x
223 | 104.24 | 20 | PS.B | HDW | Washer, Flat, SS, M5
224 | 104.25 | 20 | PS.B | HDW | Washer, Locking, Split-ring, SS, M5
221 | 104.26 | 20 | PS.B | HDW | Nut, Square, SS, 8x8x3mm, M5
206 | 151.11 | 2 | DR.FL | MECH | Extrusion, 2020 AL, 650 mm
201 | 151.12 | 2 | DR.FL | MECH | Extrusion, 2020 AL, 230 mm
213 | 151.13 | 1 | DR.FL | CER | Glass, tempered, 620 x 240 x 5mm, R=10mm
211 | 151.14 | 1.72 | DR.FL | RUB | Gasket Seal for 620 x 240 glass panel
231 | 151.15 | 4 | DR.FL | HDW | Corners
222 | 151.16 | 20 | DR.FL | HDW | Screw, MS, SHCS, SS, M5 x
223 | 151.17 | 20 | DR.FL | HDW | Washer, Flat, SS, M5
224 | 151.18 | 20 | DR.FL | HDW | Washer, Locking, Split-ring, SS, M5
221 | 151.19 | 20 | DR.FL | HDW | Nut, Square, SS, 8x8x3mm, M5
206 | 151.21 | 2 | DR.FR | MECH | Extrusion, 2020 AL, 650 mm
201 | 151.22 | 2 | DR.FR | MECH | Extrusion, 2020 AL, 230 mm
213 | 151.23 | 1 | DR.FR | CER | Glass, tempered, 620 x 240 x 5mm, R=10mm
211 | 151.24 | 1.72 | DR.FR | RUB | Gasket Seal for 620 x 240 glass panel
231 | 151.25 | 4 | DR.FR | HDW | Corners
222 | 151.26 | 20 | DR.FR | HDW | Screw, MS, SHCS, SS, M5 x
223 | 151.27 | 20 | DR.FR | HDW | Washer, Flat, SS, M5
224 | 151.28 | 20 | DR.FR | HDW | Washer, Locking, Split-ring, SS, M5
221 | 151.29 | 20 | DR.FR | HDW | Nut, Square, SS, 8x8x3mm, M5
204 | 152.1 | 2 | DR.T | MECH | Extrusion, 2020 AL, 500 mm
205 | 152.2 | 2 | DR.T | MECH | Extrusion, 2020 AL, 560 mm
212 | 152.3 | 1 | DR.T | CER | Glass, tempered, 570 x 470 x 5mm, R=10mm
211 | 152.4 | 2.08 | DR.T | RUB | Gasket Seal for 570 x 470 glass panel
231 | 152.5 | 4 | DR.T | HDW | Corners
222 | 152.6 | 20 | DR.T | HDW | Screw, MS, SHCS, SS, M5 x
223 | 152.7 | 20 | DR.T | HDW | Washer, Flat, SS, M5
224 | 152.8 | 20 | DR.T | HDW | Washer, Locking, Split-ring, SS, M5
221 | 152.9 | 20 | DR.T | HDW | Nut, Square, SS, 8x8x3mm, M5
206 | 153.1 | 2 | DR.R | MECH | Extrusion, 2020 AL, 650 mm
202 | 153.2 | 2 | DR.R | MECH | Extrusion, 2020 AL, 410 mm
214 | 153.3 | 1 | DR.R | CER | Glass, tempered, 620 x 420 x 5mm, R=10mm
211 | 153.4 | 2.08 | DR.R | RUB | Gasket Seal for 620 x 420 glass panel
231 | 153.5 | 4 | DR.R | HDW | Corners
222 | 153.6 | 20 | DR.R | HDW | Screw, MS, SHCS, SS, M5 x
223 | 153.7 | 20 | DR.R | HDW | Washer, Flat, SS, M5
224 | 153.8 | 20 | DR.R | HDW | Washer, Locking, Split-ring, SS, M5
221 | 153.9 | 20 | DR.R | HDW | Nut, Square, SS, 8x8x3mm, M5
232 | 0 | 12 |  | HDW | Hinges
225 | 0 | 48 |  | HDW | Screw, MS, SHCS, SS, M4 x
226 | 0 | 48 |  | HDW | Nut, 2020 Tee-slot, SS, M4

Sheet: roll-up
TITLE |  | ENDER 5 PRO ENCLOSURE ASSY
DWG TYPE |  | ASSY, TOP LEVEL PARTS LIST
PART NO |  | PL104300
DESIGNER |  | CHRIS LOTT
COMPANY |  | THE STUMBLER
LOCATION |  | SACHEON, SOUTH KOREA
PAGE |  | 3 of 3
ROLLED-UP / COMBINED PARTS LIST, TO PURCHASE |  |  |  |  |  |  |  |  |  |  | 25.639 |  |  | $227.46
Item | Qty | Reference | COMM | Manufacturer | PartNo | Description | xParam | yParam | zParam | Dens | Weight
201 | 4 | DR.FL, DR.FR | MECH | DONGWON TECH | AL2020x230 | Extrusion, 2020 AL, 230 mm | 230 |  |  | 0.38 | 0.350 | 300 | $1.28 | $5.12
202 | 2 | DR.R | MECH | DONGWON TECH | AL2020x410 | Extrusion, 2020 AL, 410 mm | 410 |  |  | 0.38 | 0.312 | 500 | $2.06 | $4.12
203 | 4 | FG.L, FX.R | MECH | DONGWON TECH | AL2020x460 | Extrusion, 2020 AL, 460 mm | 460 |  |  | 0.38 | 0.699 | 500 | $2.06 | $8.24
204 | 2 | DR.T | MECH | DONGWON TECH | AL2020x500 | Extrusion, 2020 AL, 500 mm | 500 |  |  | 0.38 | 0.380 | 500 | $2.06 | $4.12
205 | 6 | PS.T, PS.B, DR.T | MECH | DONGWON TECH | AL2020x560 | Extrusion, 2020 AL, 560 mm | 560 |  |  | 0.38 | 1.277 | 600 | $2.56 | $15.36
206 | 6 | DR.FL, DR.FR, DR.R | MECH | DONGWON TECH | AL2020x650 | Extrusion, 2020 AL, 650 mm | 650 |  |  | 0.38 | 1.482 | 700 | $3.00 | $18.00
207 | 4 | FG.L, FX.R | MECH | DONGWON TECH | AL2020x700 | Extrusion, 2020 AL, 700 mm | 700 |  |  | 0.38 | 1.064 | 700 | $3.00 | $12.00
211 | 12.36 | All glass panels | RUB | CH77 RUBBER |  | Gasket Seal 3mm dia, for glass panel (meter) |  |  |  |  |  | 15 | $0.30 | $4.50
212 | 1 | DR.T | CER | DAE MYEONG |  | Glass, tempered, 570 x 470 x 5mm, R=10mm | 570 | 470 | 5 | 2500 | 3.349 | 1040 | $10.00 | $10.00
213 | 2 | DR.FL, DR.FR | CER | DAE MYEONG |  | Glass, tempered, 620 x 240 x 5mm, R=10mm | 620 | 240 | 5 | 2500 | 3.720 | 860 | $8.00 | $16.00
214 | 1 | DR.R | CER | DAE MYEONG |  | Glass, tempered, 620 x 420 x 5mm, R=10mm | 620 | 420 | 5 | 2500 | 3.255 | 1040 | $10.00 | $10.00
215 | 1 | FG.L | CER | DAE MYEONG |  | Glass, tempered, 670 x 470 x 5mm, R=10mm | 670 | 470 | 5 | 2500 | 3.936 | 1140 | $11.00 | $11.00
216 | 1 | PS.K | CER | DAE MYEONG |  | Glass, tempered, 670 x 570 x 5mm, R=10mm | 670 | 570 | 5 | 2500 | 4.774 | 1240 | $11.00 | $11.00
221 | 180 | All corners | HDW | SAMDI |  | Nut, Square, Steel, 8x8x3mm, M5 |  |  |  |  |  | 200 | $0.10 | $20.00
222 | 180 | All corners | HDW | YOUNGWON TOOL |  | Screw, MS, SHCS, SS, M5 x 12mm |  |  |  |  |  | 200 | $0.06 | $12.00
223 | 180 | All corners | HDW | YOUNGWON TOOL |  | Washer, Flat, SS, M5 |  |  |  |  |  | 200 | $0.03 | $6.00
224 | 180 | All corners | HDW | YOUNGWON TOOL |  | Washer, Locking, Split-ring, SS, M5 |  |  |  |  |  | 200 | $0.02 | $4.00
225 | 48 | All corners | HDW | YOUNGWON TOOL |  | Screw, MS, SHCS, SS, M4 x 8mm |  |  |  |  |  | 50 | $0.04 | $2.00
226 | 48 | All hinges | HDW | DONGWON TECH |  | Nut, 2020 Tee-slot, SS, M4 |  |  |  |  |  | 50 | $0.18 | $9.00
231 | 36 | All hinges | HDW | ALI-GROUNDHOG | 2020-CORNER-AL | Corners | 10.725 | 10.725 | 10.725 | 2.7 | 1.042 | 36 | $1.25 | $45.00
232 | 12 | DR.FL, DR.FR, DR.R, DR.T | HDW | MYEONGGA | HC4040-CAST | Hinges |  |  |  |  |  | 12 | $4.35 | $52.20
 |  |  |  |  |  |  |  |  |  |  |  | 2480
 |  |  |  |  |  |  |  |  |  |  |  | 1720
 |  |  |  |  |  |  |  |  |  |  |  | 1720
 |  |  |  |  |  |  |  |  |  |  |  | 2080
 |  |  |  |  |  |  |  |  |  |  |  | 2280
 |  |  |  |  |  |  |  |  |  |  |  | 2080

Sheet: SMT SIZES
ENGLISH | METRIC | SIZE (INCHES) |  | SIZE (MILLIMETERS)
01005 | 0402 | 0.016 | 0.008 | 0.40 | 0.20
0201 | 0603 | 0.024 | 0.012 | 0.60 | 0.30
0402 | 1005 | 0.040 | 0.020 | 1.00 | 0.50
0603 | 1608 | 0.063 | 0.031 | 1.60 | 0.80
0805 | 2013 | 0.080 | 0.050 | 2.00 | 1.25
1008 | 2520 | 0.100 | 0.080 | 2.50 | 2.00
1206 | 3216 | 0.126 | 0.063 | 3.20 | 1.60
1210 | 3225 | 0.126 | 0.100 | 3.20 | 2.50
1808 | 4516 | 0.177 | 0.063 | 4.50 | 1.60
1812 | 4532 | 0.180 | 0.120 | 4.50 | 3.20
2010 | 5025 | 0.200 | 0.100 | 5.00 | 2.50
2512 | 6431 | 0.250 | 0.120 | 6.35 | 3.05

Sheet: COMMODITY CODES
IC | Integrated
MCD | Integrated Circuit, Digital
MCA | Integrated Circuit, Analog (or combination)
SEM | Semiconductors (transistor, diodes, LED, etc.)
OSC | Crystals and Oscillators
CAP | Capacitors
RES | Resistors
IND | Inductors, Transformers, Ferrites
FUS | Fuses and circuit breakers
CON | Connectors, plugs, jacks, headers, etc.
SWI | Switches, Pushbuttons
ASY | Sub-Assemblies
HDW | Hardware, screws, feet, brackets, etc.
MSC | Miscellaneous
NUL | Nothing (e.g., fiducial, test point, etc.)
MECH | Mechanical structure
CER | Glass and ceramic
RUB | Rubber, Neoprene, etc.

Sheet: THREADS
Metric | Basic | Coarse | Approx | Matching | Basic | UNC | UNF
Thread | Dia (in) | Pitch | TPI | UTS Size | Dia (in) | TPI | TPI
M2 | 0.079 | 0.4 | 63 | #2 | 0.086 | 56 | 64
M3 | 0.118 | 0.5 | 50 | #4 | 0.112 | 40 | 48
M3.5 (*) | 0.138 | 0.6 | 42 | #6 | 0.138 | 32 | 40
M4 | 0.157 | 0.7 | 36 | #8 | 0.164 | 32 | 36
M5 | 0.197 | 0.8 | 32 | #10 | 0.190 | 24 | 32
M6 | 0.236 | 1.0 | 25 | 1/4 | 0.250 | 20 | 28
UTS-Unified Thread Standard (Used in USA and Canada)
UNC - Unified National Coarse
UNF - Unified National Fine
TPI - Threads per Inch
(*) non-standard size?

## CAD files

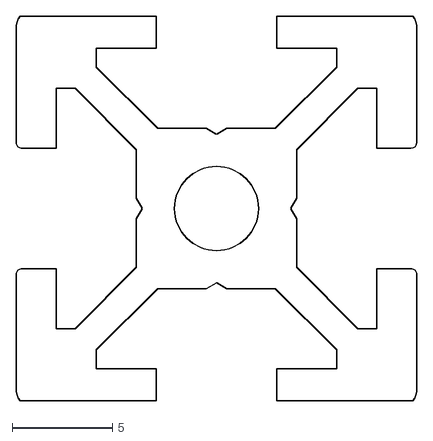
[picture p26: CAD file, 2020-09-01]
uses/2020.dxf
20.0 x 19.2

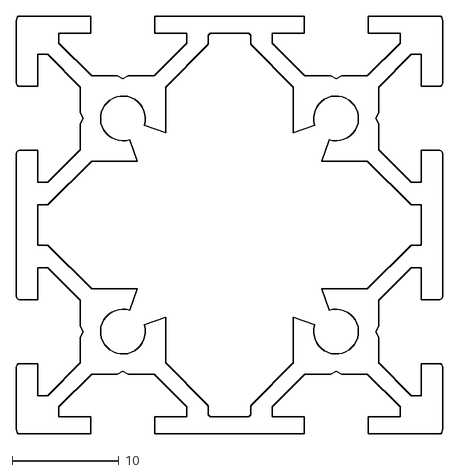
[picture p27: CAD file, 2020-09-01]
uses/4040.dxf
40.0 x 39.2

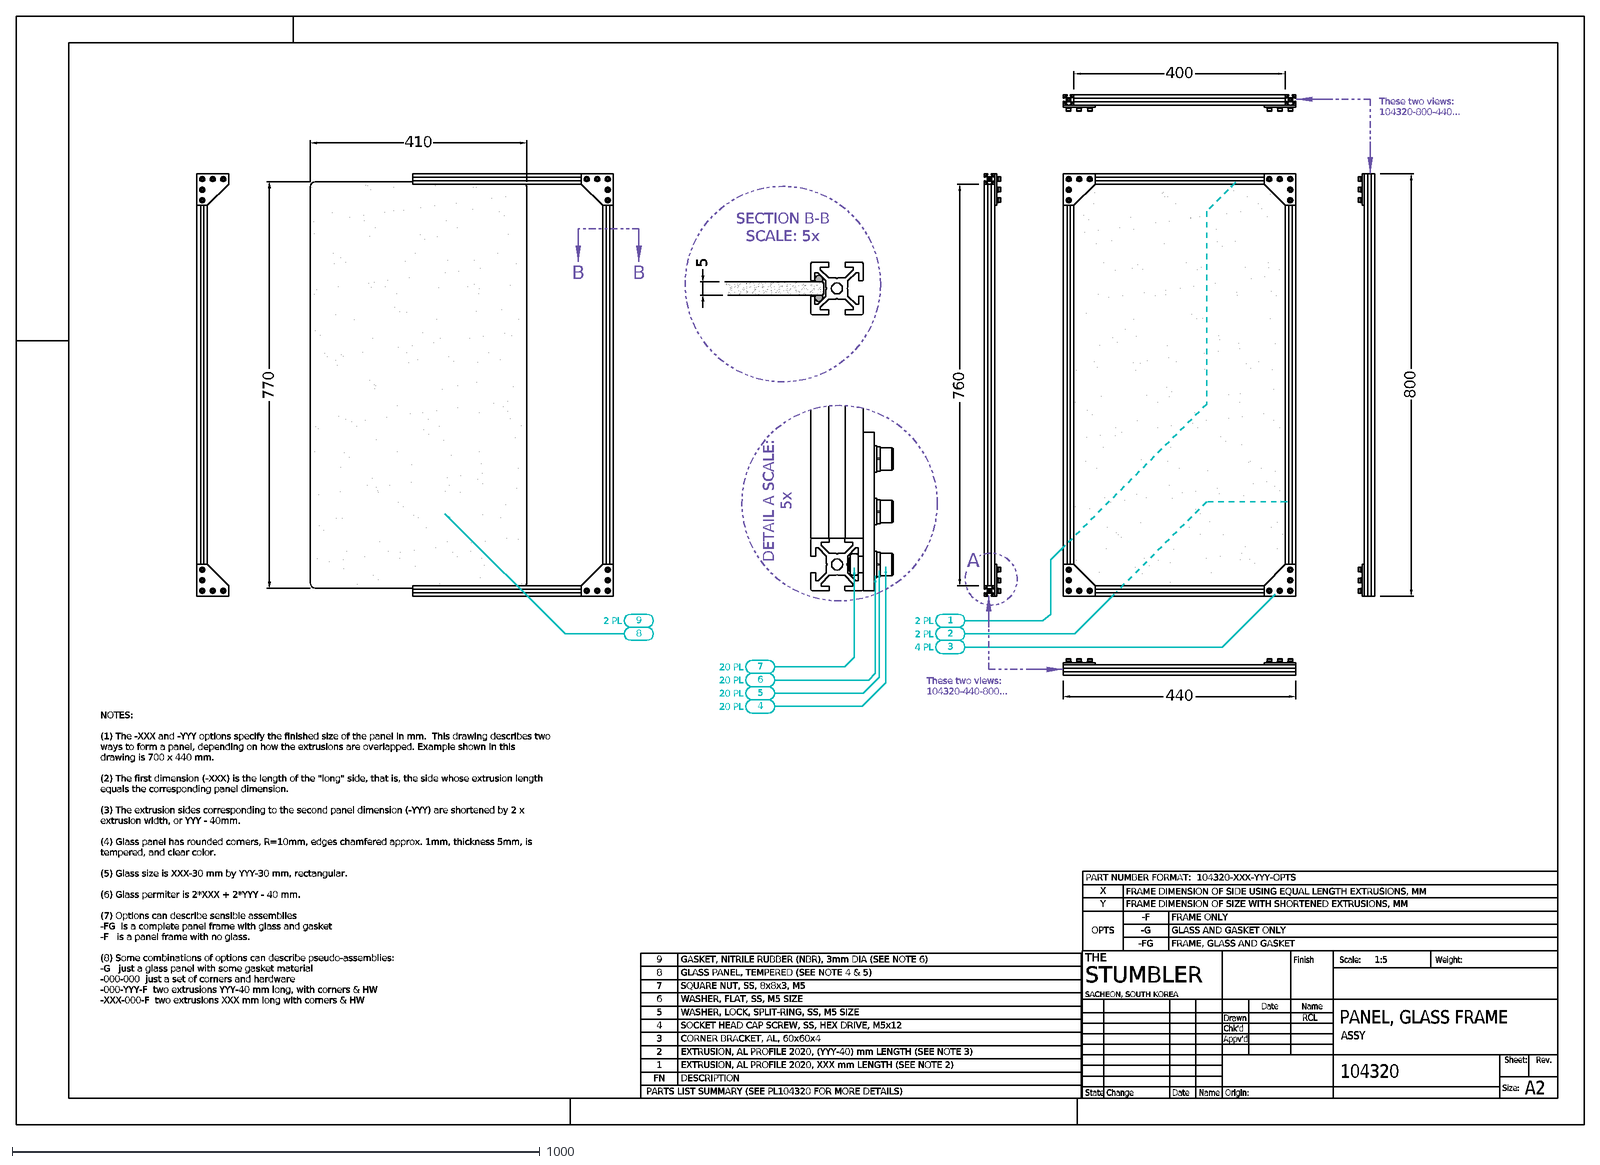
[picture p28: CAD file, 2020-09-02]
cage-panel.dxf
400
800
410
770
5
PART NUMBER FORMAT: 104320-XXX-YYY-OPTS
X
FRAME DIMENSION OF SIDE USING EQUAL LENGTH EXTRUSIONS, MM
Y
FRAME DIMENSION OF SIZE WITH SHORTENED EXTRUSIONS, MM
OPTS
-F
FRAME ONLY
-G
GLASS AND GASKET ONLY
-FG
FRAME, GLASS AND GASKET
6
4
9
8
1
2
3
2 PL
4 PL
20 PL
7
A
DETAIL A SCALE: 5x
B
SECTION B-B SCALE: 5x
GASKET, NITRILE RUBBER (NBR), 3mm DIA (SEE NOTE 6)
GLASS PANEL, TEMPERED (SEE NOTE 4 & 5)
SQUARE NUT, SS, 8x8x3, M5
WASHER, FLAT, SS, M5 SIZE
WASHER, LOCK, SPLIT-RING, SS, M5 SIZE
SOCKET HEAD CAP SCREW, SS, HEX DRIVE, M5x12
CORNER BRACKET, AL, 60x60x4
EXTRUSION, AL PROFILE 2020, (YYY-40) mm LENGTH (SEE NOTE 3)
EXTRUSION, AL PROFILE 2020, XXX mm LENGTH (SEE NOTE 2)
FN
DESCRIPTION
PARTS LIST SUMMARY (SEE PL104320 FOR MORE DETAILS)
NOTES: (1) The -XXX and -YYY options specify the finished size of the panel in mm. This drawing describes two ways to form a panel, depending on how the extrusi
These two views: 104320-800-440...
These two views: 104320-440-800...
440
760
104320
PANEL, GLASS FRAME
ASSY
1:5
RCL
A2
State
Drawn
Appv'd
Name
Origin: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

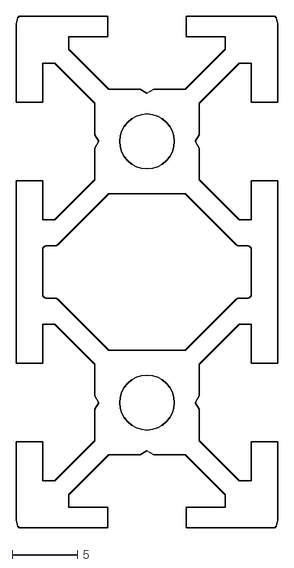
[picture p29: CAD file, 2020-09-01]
uses/2040.dxf
20.0 x 39.2

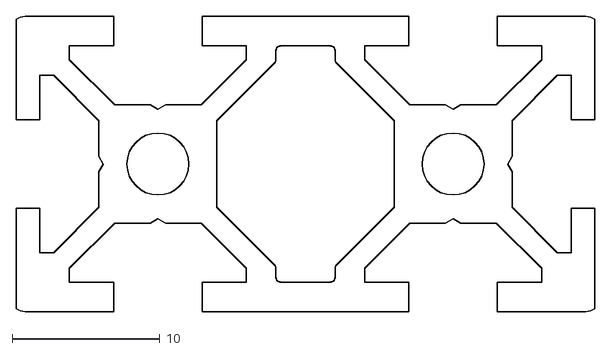
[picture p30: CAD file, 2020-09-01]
uses/4020.dxf
39.2 x 20.0

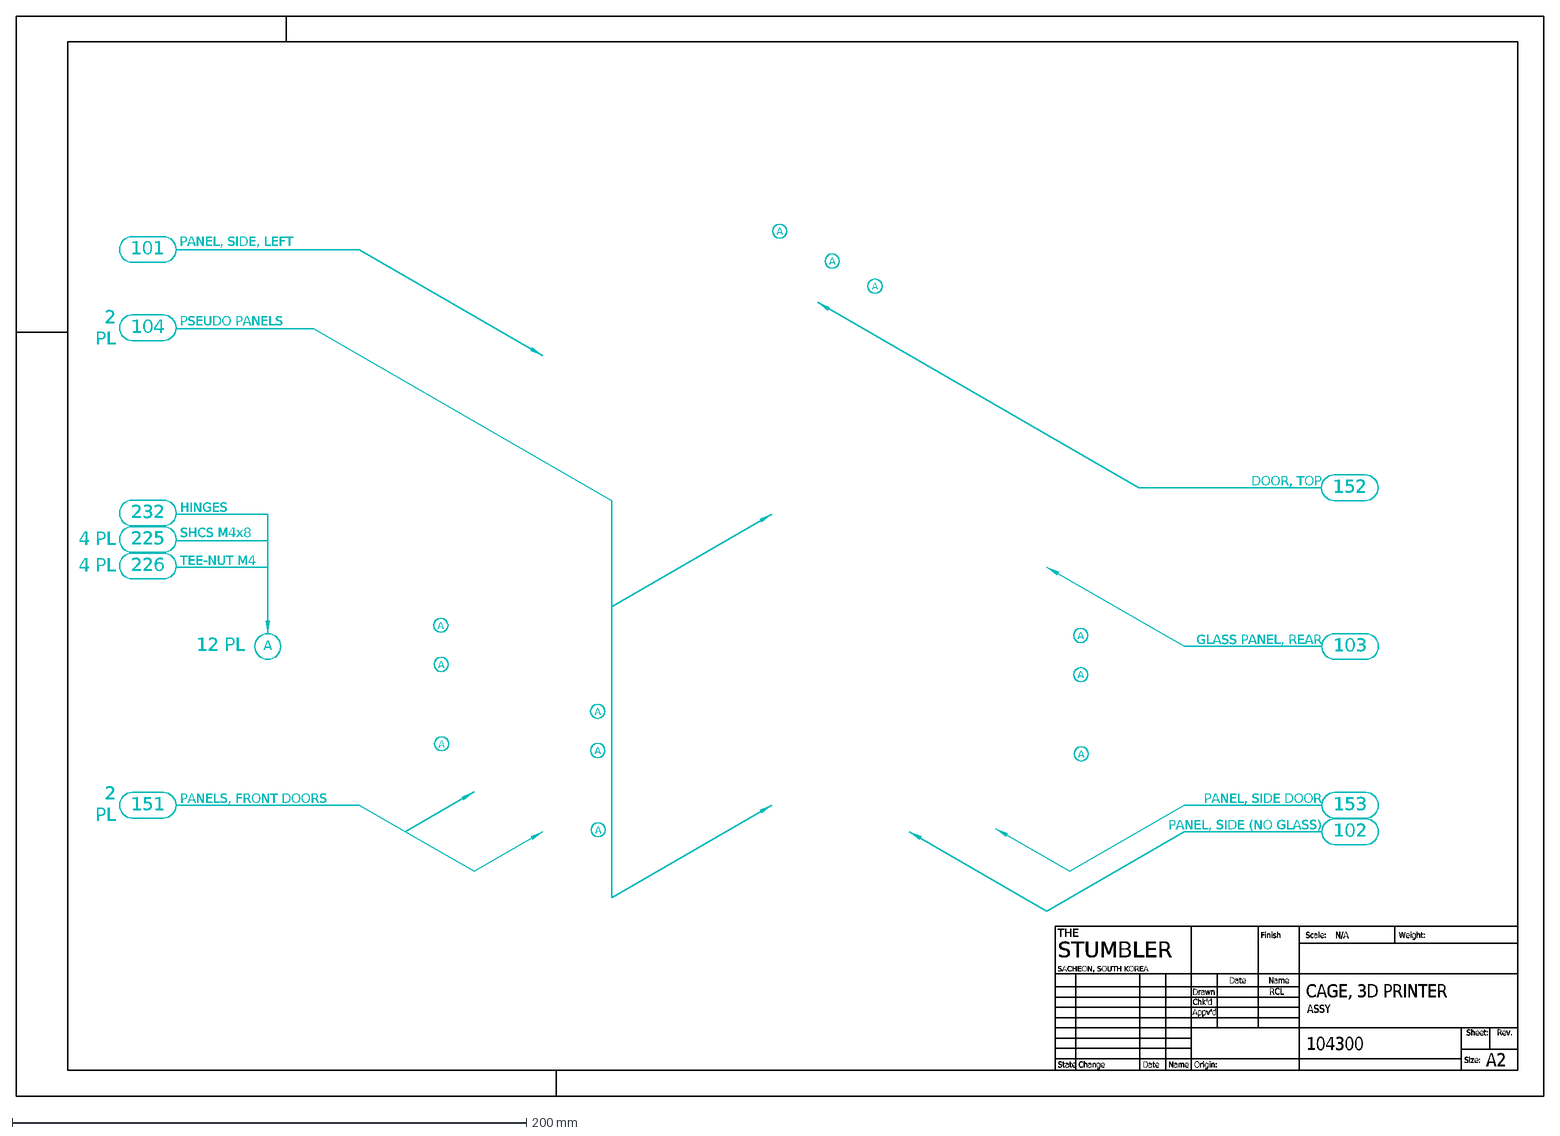
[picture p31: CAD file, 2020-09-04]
104300-cage-exploded.dxf
151
2 PL
PANELS, FRONT DOORS
101
PANEL, SIDE, LEFT
103
104
GLASS PANEL, REAR
PSEUDO PANELS
102
153
PANEL, SIDE DOOR
PANEL, SIDE (NO GLASS)
152
DOOR, TOP
232
225
4 PL
226
HINGES
SHCS M4x8
TEE-NUT M4
A
12 PL
104300
CAGE, 3D PRINTER
ASSY
N/A
RCL
A2
State
Drawn
Appv'd
Name
Origin:
Chk'd
Date
Change
Finish
Scale:
Weight:
Sheet:
Size:
Rev.
THE STUMBLER
SACHEON, SOUTH KOREA

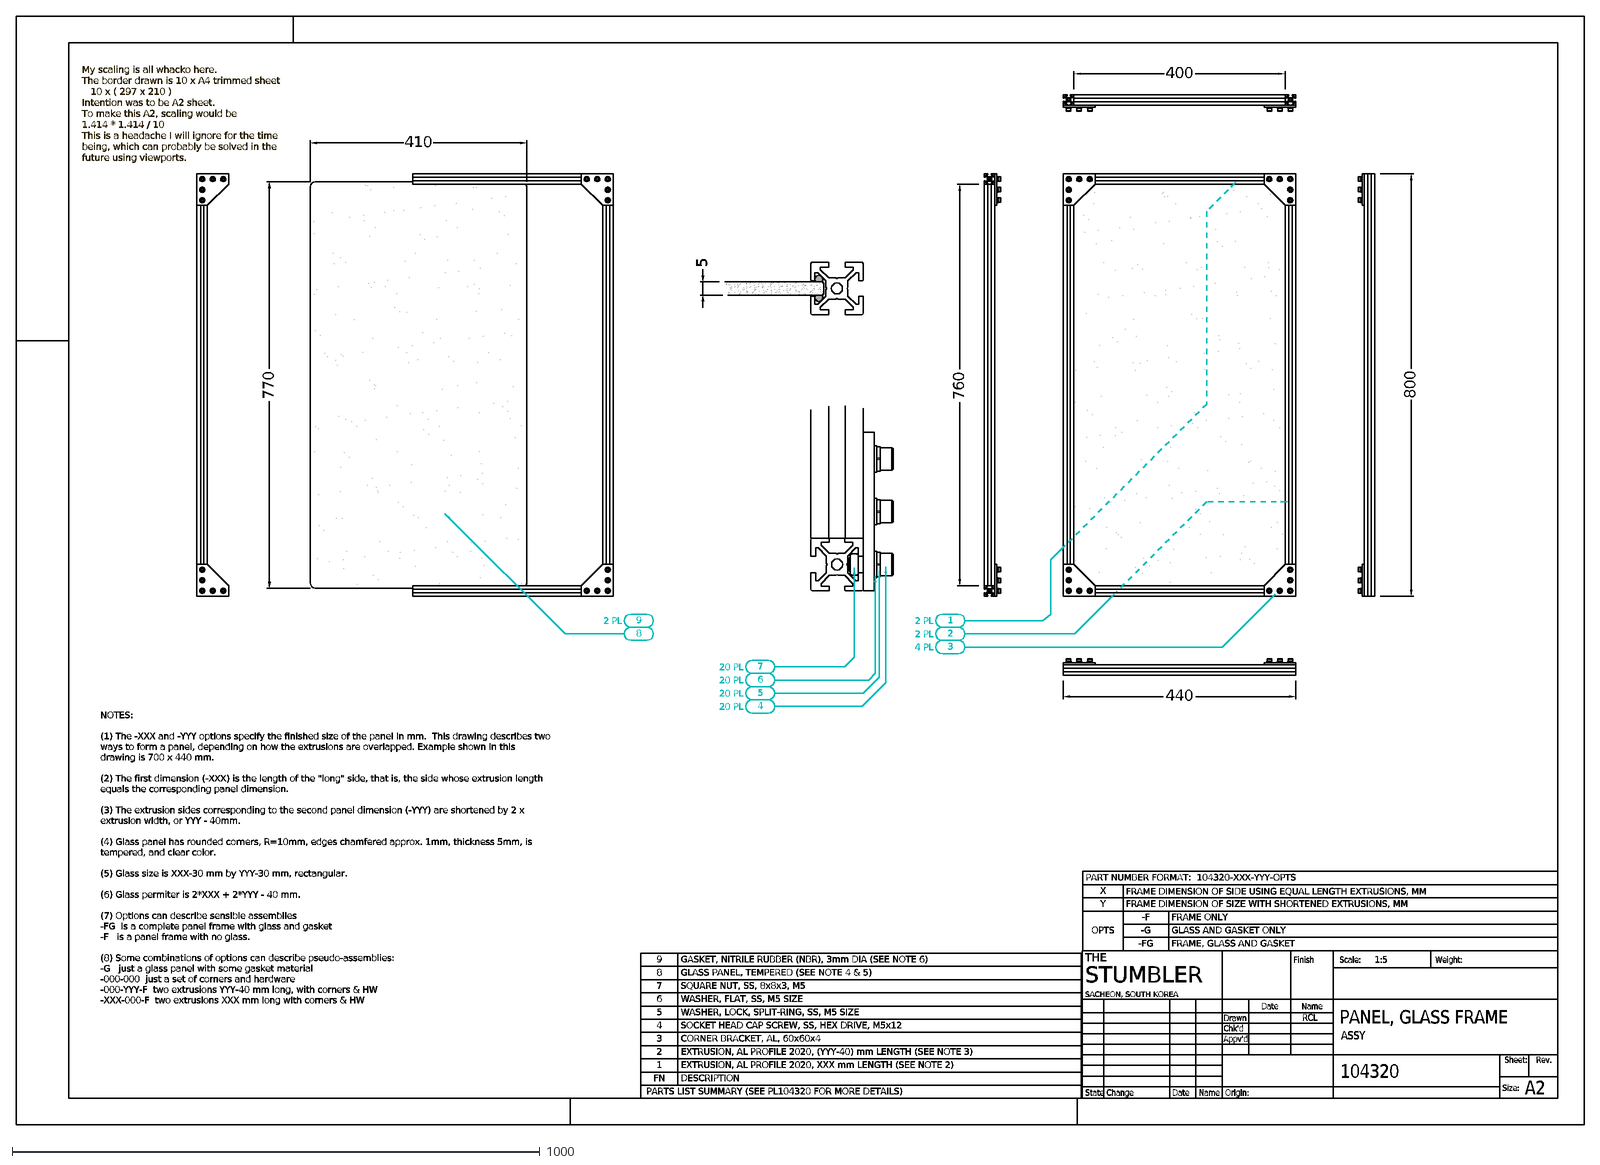
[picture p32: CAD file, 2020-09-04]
104320-cage-panel.dxf
400
800
410
770
5
PART NUMBER FORMAT: 104320-XXX-YYY-OPTS
X
FRAME DIMENSION OF SIDE USING EQUAL LENGTH EXTRUSIONS, MM
Y
FRAME DIMENSION OF SIZE WITH SHORTENED EXTRUSIONS, MM
OPTS
-F
FRAME ONLY
-G
GLASS AND GASKET ONLY
-FG
FRAME, GLASS AND GASKET
6
4
9
8
1
2
3
2 PL
4 PL
20 PL
7
GASKET, NITRILE RUBBER (NBR), 3mm DIA (SEE NOTE 6)
GLASS PANEL, TEMPERED (SEE NOTE 4 & 5)
SQUARE NUT, SS, 8x8x3, M5
WASHER, FLAT, SS, M5 SIZE
WASHER, LOCK, SPLIT-RING, SS, M5 SIZE
SOCKET HEAD CAP SCREW, SS, HEX DRIVE, M5x12
CORNER BRACKET, AL, 60x60x4
EXTRUSION, AL PROFILE 2020, (YYY-40) mm LENGTH (SEE NOTE 3)
EXTRUSION, AL PROFILE 2020, XXX mm LENGTH (SEE NOTE 2)
FN
DESCRIPTION
PARTS LIST SUMMARY (SEE PL104320 FOR MORE DETAILS)
NOTES: (1) The -XXX and -YYY options specify the finished size of the panel in mm. This drawing describes two ways to form a panel, depending on how the extrusi
440
760
104320
PANEL, GLASS FRAME
ASSY
1:5
RCL
A2
State
Drawn
Appv'd
Name
Origin:
Chk'd
Date
Change
Finish
Scale:
Weight: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

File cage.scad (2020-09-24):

include <nopscad/lib.scad>

use <./uses/printed_flat_hinge.scad>
use <./uses/customizable_aluminium_extrusion_plate_brackets.scad>
use <./uses/alpha/alpha.scad>


// These control the presentation, these variables have to be set.
// They have to be manually changed?
//
// type of view: [ $t, animate, explode_me, label_me ]
function get_tbucks(a) = a[0];
function get_animate(a) = a[1];
function get_explode_me(a) = a[2];
function get_label_me(a) = a[3];

// view point:   [ $vpr, $vpd, $vpt ]
function get_vpr(a) = a[0];
function get_vpd(a) = a[1];
function get_vpt(a) = a[2];


// some pre-defined view types
view_exploded =                  [ 1, 0, 1, 0 ];
view_exploded_assy_lines =       [ 0, 0, 1, 0 ];
view_exploded_labels =           [ 0, 0, 1, 1 ];
view_normal =                    [ 1, 0, 0, 0 ];
view_animated =                  [ 0, 1, 1, 0 ];


// some pre-defined views
iso1 = 45.0;
iso2 = 90.0 - asin(1.0/sqrt(3.0));
view_iso = [ [iso2,0,iso1], 8000, [0,250,250] ];


//========================================================================
// Select view type and view point
//========================================================================
// There's an issue with animation, which I can't solve without editing
// these input more than I had hoped for...

// 1. Select view point
view_point = view_iso;

// 2. Select view type
// view_type = view_exploded_assy_lines;
//view_type = view_exploded;
view_type = view_exploded_labels;
//view_type = view_normal;
//view_type = view_animated;

// 3. Select optional drawing features
draw_axes = false;
draw_dimensions = false;
draw_iso_grids = false;
draw_ghost = true;

//----------------------------------------
// Apply the view type and view point
//$t = get_tbucks(view_type);
animate = get_animate(view_type);
explode_me = get_explode_me(view_type);
label_me = get_label_me(view_type);

$vpr = get_vpr(view_point); // rotation
$vpd = get_vpd(view_point); // camera distance
$vpt = get_vpt(view_point); // translation


//========================================================================
//=== Make a poor-man's BOM of the assembly
//========================================================================
// Normally, this is only generated when run from the command line,
// such as (see script mkbom.sh):
// $ openscad -D 'bom=true' -o bom.echo enc.scad 
TAB = chr(9);
bom=false;
module mkbom( string ) {
  if(bom) echo( str( "BOM", TAB, string ) );
}


//========================================================================
//=== Simple Utility Functions
//========================================================================

// calculates the volume in m^3, 
// note that the inputs are in mm
function volume(a) = a.x*a.y*a.z / 1.0e9;

// calculates mass using volumen (m^3) 
// and density, kg / m^3
function mass(a,d) = d*volume(a);

// calculates the perimeter, 
// used to estimate gasket material qty
function perimeter(a) = a.x+a.x+a.y+a.y;

// calculates the area in m^2, 
// note that the inputs are in mm
function area(a) = a.x*a.y / 1.0e6;

module rounded_tube( length, dia ) {
  translate([0,0,0.5*dia]) {
    sphere(d=dia);
    cylinder( h=length-dia, d=dia, center=false);
    translate([0,0,length-dia]) sphere(d=dia);
  }
}

//========================================================================
//=== Makes a "ghost" cube, useful for checking things
//========================================================================
ghost_dia=3;
ghost_color="GreenYellow";
ghost_alpha=0.25;
ghost_border="Black";
module make_ghost_simple( size, ctr ) {
  %cube([size.x,size.y,size.z], center=ctr);
}

module make_ghost( size, ctr ) {
  color(ghost_color, ghost_alpha) 
    translate(0.5*[gasket_dia,gasket_dia,gasket_dia])
    cube(size-[gasket_dia,gasket_dia,gasket_dia], center=ctr);
    //cube([size.x,size.y,size.z], center=ctr);

  color(ghost_border) {
    translate([0.5*ghost_dia,0.5*ghost_dia,0])
    rounded_tube(size.z, ghost_dia);
    translate([0.5*ghost_dia,size.y-0.5*ghost_dia,0])
      rounded_tube(size.z, ghost_dia);
    translate([size.x-0.5*ghost_dia,+0.5*ghost_dia,0])
      rounded_tube(size.z, ghost_dia);
    translate([size.x-0.5*ghost_dia,size.y-0.5*ghost_dia,0])
      rounded_tube(size.z, ghost_dia);

    translate([0,0.5*ghost_dia,0.5*ghost_dia])
    rotate(90,[0,1,0])
      rounded_tube(size.x, ghost_dia);

    translate([0.5*ghost_dia,0,0.5*ghost_dia])
      rotate(-90,[1,0,0])
        rounded_tube(size.y, ghost_dia);

    translate([0,size.y-0.5*ghost_dia,0.5*ghost_dia])
    rotate(90,[0,1,0])
      rounded_tube(size.x, ghost_dia);

    translate([size.x-0.5*ghost_dia,0,0.5*ghost_dia])
      rotate(-90,[1,0,0])
        rounded_tube(size.y, ghost_dia);


    translate([0,0.5*ghost_dia,size.z-0.5*ghost_dia])
    rotate(90,[0,1,0])
      rounded_tube(size.x, ghost_dia);

    translate([0.5*ghost_dia,0,size.z-0.5*ghost_dia])
      rotate(-90,[1,0,0])
        rounded_tube(size.y, ghost_dia);

    translate([0,size.y-0.5*ghost_dia,size.z-0.5*ghost_dia])
    rotate(90,[0,1,0])
      rounded_tube(size.x, ghost_dia);

    translate([size.x-0.5*ghost_dia,0,size.z-0.5*ghost_dia])
      rotate(-90,[1,0,0])
        rounded_tube(size.y, ghost_dia);

  }

}



//========================================================================
//=== Aluminum Extrusions
//========================================================================
ex2020 = [20,20, "uses/2020.dxf", "ex2020", 0.38];
ex2040 = [20,40, "uses/2040.dxf", "ex2040", 0.00]; // TODO mass
ex4020 = [40,20, "uses/4020.dxf", "ex4020", 0.00]; // TODO mass
ex4040 = [40,40, "uses/4040.dxf", "ex4040", 0.00]; // TODO mass
function ex_name(ex) = ex[3];
function ex_filename(ex) = ex[2];

color_panel = "Silver";
// extrusion mass is given by the manufacturer
// as kg / length.  Note: length is mm
function ex_mass(ex,l) = (l*ex[4]) / 1.0e3;

//-------
// Generates a piece of AL extrusion along the Z axis
//-------
// Labels are optional and controlled by label_me variable
// used with exploded view to make a diagram helpful for assembly
lasf=7; // label scale factor
lacol="Red"; // label color
lacol2="LimeGreen"; // label background color
lacol3="Purple"; // label border color
module extrusion( ex, h, adj="", overunder=1.0 ) {
  mkbom( str(ex_name(ex), adj, TAB, h, TAB, ex_mass(ex,h)) );
  color(color_panel)
  linear_extrude(height=h)
    import(ex_filename(ex));

  // puts a label by each extrusion, 
  // it is an aid for assembly
  if(label_me) {
    translate([overunder*lasf*10,-0.5*ex.x,0.5*h-0.5*lasf*getwid(str(h)) ])
    rotate(90,[1,0,0])
    rotate(90,[0,0,1])
    scale([lasf,lasf,lasf]) {
      color(lacol)
          alpha_draw_string( 0, -5, 0, str(h), $cross=1);
      color(lacol2)
        translate([1,-4,-0.5])
          cube([getwid(str(h)),9,1]);
      difference() {
      color(lacol3) 
        translate([0,-5,-0])
          cube([2+getwid(str(h)),11,1]);
        translate([1,-4,-2])
          cube([getwid(str(h)),9,4]);
      }
    }
  }
}


//========================================================================
//=== Generate flat 2D corner joiner plates
//========================================================================
// Using corner brackets from user mightynozzle
// https://www.thingiverse.com/thing:2503622
// https://mightynozzle.com
color_corner = "Purple";

module flat_2d_corner(adj="") {
  mkbom(str("corner", adj, TAB, 5)); // number of screws per corner, M5
  aluminium_extrusion_bracket(
    shape = "L", type = "uniform", 
    bracket_height_in_millimeter = 7.0,
    support = "full", preview_color = color_corner
  );
}

// put the corner on the "top" of a panel
module posn_corner_top() {
  translate([60,60,20])
    rotate(180,[0,0,1])
    children();
}

// put the corner on the "bottom" of a panel
module posn_corner_bottom() {
  translate([60,60,0])
    rotate(-90,[0,0,1])
    rotate(180,[1,0,0])
    children();
}

// place a corner depending on the argument
module posn_corner(placement, adj="") {
  if( placement == "top" ) posn_corner_top() flat_2d_corner(adj);
  if( placement == "bottom" ) posn_corner_bottom() flat_2d_corner(adj);
}

//========================================================================
//=== Make Gasketing
//========================================================================
gasket_color = "Black";
gasket_dia = 4; // mm
gasket_overlap = 0; // mm
module gasket_strip( length, dia ) {
  rounded_tube( length, dia );
}

module gasket_rectangle( size, dia ) {
  translate([ gasket_overlap, 0.5*dia+gasket_overlap, 0])
  rotate(90,[0,1,0])
    gasket_strip( size.x-2*gasket_overlap, dia);

  translate([ 0.5*dia+gasket_overlap, gasket_overlap, 0])
  rotate(-90,[1,0,0])
    gasket_strip( size.y-2*gasket_overlap, dia);

  translate([ gasket_overlap, size.y-0.5*dia-gasket_overlap, 0])
  rotate(90,[0,1,0])
    gasket_strip( size.x-2*gasket_overlap, dia);
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

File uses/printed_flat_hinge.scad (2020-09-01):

//
// NopSCADlib Copyright Chris Palmer 2018
// nop.head@gmail.com
// hydraraptor.blogspot.com
//
// This file is part of NopSCADlib.
//
// NopSCADlib is free software: you can redistribute it and/or modify it under the terms of the
// GNU General Public License as published by the Free Software Foundation, either version 3 of
// the License, or (at your option) any later version.
//
// NopSCADlib is distributed in the hope that it will be useful, but WITHOUT ANY WARRANTY;
// without even the implied warranty of MERCHANTABILITY or FITNESS FOR A PARTICULAR PURPOSE.
// See the GNU General Public License for more details.
//
// You should have received a copy of the GNU General Public License along with NopSCADlib.
// If not, see <https://www.gnu.org/licenses/>.
//

//
//! A parametric flat hinge. A piece of filament can be used for the hinge pin.
//!
//! The width, depth, thickness, number and type of screws, number of knuckles, knuckle diameter, pin diameter and clearance can all be varied.
//! A margin between the screws and the knuckle edge can be enforced to allow the hinge to bend all the way back to 270&deg; from closed.
//!
//! Opening the test in OpenSCAD with its customiser enabled allows these parameters to be played with.
//!
//! Note setting ```thickness1``` or ```thickness2``` to zero in the ```hinge_fastened_assembly()``` removes the screws from one side or the other and
//! setting ```show_hinge``` to false removes the hinge.
//! This allows the hinges and one set of screws to belong to one assembly and the other set of screws to another assembly.
//
include <nopscad/core.scad>
include <nopscad/vitamins/screws.scad>

function hinge_width(type)       = type[1]; //! Width
function hinge_depth(type)       = type[2]; //! Depth of each leaf
function hinge_thickness(type)   = type[3]; //! Thickness of the leaves
function hinge_pin_dia(type)     = type[4]; //! The pin diameter
function hinge_knuckle_dia(type) = type[5]; //! The knuckle diameter
function hinge_knuckles(type)    = type[6]; //! How many knuckles
function hinge_screw(type)       = type[7]; //! Screw type to mount it
function hinge_screws(type)      = type[8]; //! How many screws
function hinge_clearance(type)   = type[9]; //! Clearance between knuckles
function hinge_margin(type)      = type[10]; //! How far to keep the screws from the knuckes
function hinge_pitch(type) = type[11]; //! spacing between screw holes
function hinge_color(type) = type[12]; //! Hinge color

function hinge_radius(type)      = washer_radius(screw_washer(hinge_screw(type))) + 1;

module hinge_screw_positions(type) { //! Place children at the screw positions
    screws = hinge_screws(type);
    w = hinge_width(type);
    d = hinge_depth(type);
    r = hinge_radius(type);
    m = hinge_margin(type);
    pitch = hinge_pitch(type);
    assert(screws > 1, "must be at least two screws");
    w_pitch = (w - 2 * r) / (screws - 1);
    d_pitch = d - 2 * r - m;
    wr = washer_radius(screw_washer(hinge_screw(type)));

    for(i = [0 : screws - 1])
        //translate([-(w-pitch)/2 + i*pitch, -d ])
        translate([-pitch/2 + i*pitch, d/2 ])
            children();
}

module hinge_male(type, female = false) {       //! The half with the stationary pin
    stl(str("hinge_", female ? "fe": "", "male_", type[0]));

    r = hinge_radius(type);
    w = hinge_width(type);
    t = hinge_thickness(type);
    kr = hinge_knuckle_dia(type) / 2;
    pr = hinge_pin_dia(type) / 2;
    assert(kr > pr, "knuckle diameter must be bigger than the pin diameter");

    n = hinge_knuckles(type);
    assert(n >= 3, "must be at least three knuckes");
    mn = ceil(n / 2);                           // Male knuckles
    fn = floor(n / 2);                          // Female knuckles
    gap = hinge_clearance(type);
    mw = (w - (n - 1) * gap) / 2 / mn;          // Male knuckle width
    fw = (w - (n - 1) * gap) / 2 / fn;          // Female knuckle width

    teardrop_r = kr / cos(22.5);                // The corner on the teardrop
    inset = sqrt(sqr(teardrop_r + gap) - sqr(kr - t)) - kr;

    linear_extrude(height =t)
        difference() {
            hull() {
                for(side = [-1, 1])
                    translate([side * (w / 2 - r), hinge_depth(type) - r])
                        circle4n(r);

                translate([-w / 2, inset])
                    square([w, eps]);
            }
            hinge_screw_positions(type)
                poly_circle(screw_clearance_radius(hinge_screw(type)), 60);
        }

    pitch = mw + gap + fw + gap;
    dir = female ? -1 : 1;
    translate([0, -kr, kr])
        rotate([90, 0, -90])
            for(z = [0 : (female ? fn : mn) - 1])
                translate_z(-dir * w / 2 + z * dir * pitch + (female ? -fw - mw - gap : 0))
                    linear_extrude(height = female ? fw : mw)
                        difference() {
                            hull() {
                                rotate(180)
                                    teardrop(r = kr, h = 0);

                                translate([-kr - 1, -kr])
                                    square(1);
                            }
                            teardrop_plus(r = pr + (female ? gap : 0), h = 0);
                        }
}

module hinge_female(type) hinge_male(type, true);

module hinge_both(type) { //! Both parts together for printing
    translate([0, +0.5*hinge_knuckle_dia(type)])
      hinge_male(type);

    translate([0, -0.5*hinge_knuckle_dia(type)])
      rotate(180)
        hinge_female(type);
}

module hinge_assembly(type, angle = 0)
assembly(str("hinge_", type[0])) { //! Assembled hinge
    kr = hinge_knuckle_dia(type) / 2;
    hr = hinge_pin_dia(type) / 2;
    w = hinge_width(type);
    col = hinge_color(type);

    vitamin(str(": Hinge pin ", w, " x ", 2 * hr, "mm"));
    translate([0, kr, 0])
      color(col) hinge_male(type);

    translate([0, 0, kr])
        rotate([0, 90, 0])
            explode(w + 10)
                color("silver") cylinder(r = hr , h = w, center = true);

    translate([0, 0, kr])
        rotate([-angle, 0, 0])
            translate([0, -kr, -kr])
                rotate(180)
                     color(col) hinge_female(type);
}

module hinge_fastened_assembly(type, thickness1, thickness2, angle, show_hinge = true) { //! Assembled hinge with its fasteners
    if(show_hinge)
        hinge_assembly(type, angle);

    screw = hinge_screw(type);
    washer_t = 2 * washer_thickness(screw_washer(screw));
    nut = screw_nut(screw);
    nut_t = nut_thickness(nut, true);
    t = hinge_thickness(type);
    kr = hinge_knuckle_dia(type) / 2;

    module fasteners(thickness)
        if(thickness)
            hinge_screw_positions(type) {
                translate_z(t)
                    screw_and_washer(screw, screw_longer_than(t + thickness + washer_t + nut_t));

                translate_z(-thickness)
                    vflip()
                        nut_and_washer(nut, true);
            }

    translate([0, kr, 0])
    fasteners(thickness1);

    translate([0, -kr, kr])
        rotate([-angle, 0, 0])
            translate([0, 0, -kr])
                rotate(180)
                     fasteners(thickness2);
}

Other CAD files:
uses/customizable_aluminium_extrusion_plate_brackets.scad
uses/alpha/alpha.scad
104300-cage-exploded.dwg
104320-cage-panel.dwg
uses/alpha/arc.scad
uses/alpha/ascii.scad

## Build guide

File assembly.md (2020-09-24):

# Enclosure for 3D Printer, Assembly Steps

## Tools

Here is a list of the tools needed to assemble the enclosure:

* Hex Ball Drivers
  - 4 mm, used for M5 Socket head machine screws
  - 3 mm, used for M4 Socket head machine screws
  - 2.5 mm, used for M4 Flat Head screws
 
* M4 tap, for threading holes in the vertical posts

## Basic Plan

Individual panels are assembled first.  These are then assembled into a
cube and the rear glass is installed.  Finally, the door panels are
mounted on their hinges, and accessories like handles and latches are
installed.

  1. Make the Normal Panels
  2. Make the Oddball Panels
  3. Join the Left and Right Sides
  4. Install the Doors
  5. Accessories
  6. Optional, Future Accessories

## 1. Make the Normal Panels

The cage is composed of several pre-made panels.
Build the normal ones first, per the assembly drawing 104320.  

* FG.L - Left side panel (frame with glass)
* DR.FL - Front door, left (frame with glass)
* DR.FR - Front door, right (frame with glass)
* DR.R - Right side door (frame with glass)
* DR.T - Top door (frame with glass)

The dimensions of each panel are in the BOM spreadsheet.
The dimensions of each item in a given panel are also in the BOM, 
in the worksheet called "roll-down".

My assembly process was to assemble a "C" shape frame first.
Then slide the glass panel in the groove, along with rubber gasket
material, and finally install the fourth frame side to complete the
panel.

In addition to the square nuts required for the corner brackets,
other square nuts may be required for other, top-level, assembly steps.
If you forget, it's not a show-stopper.  You can open a corner and
insert missing square nuts later on in the process, but that's awkward.
These extra nuts are marked on the top-level assembly drawing (TBD).

#### Example corner before installation
Example corner before installation

#### Frame corner detail
Detail view of assembled frame corner

#### Corner can slide
Corner can slide

#### Better not forget the square nuts
Better not forget the square nuts

#### Too many square nuts
Too many square nuts

#### Completed front door panel
Completed front door panel

#### Glass panels assembled
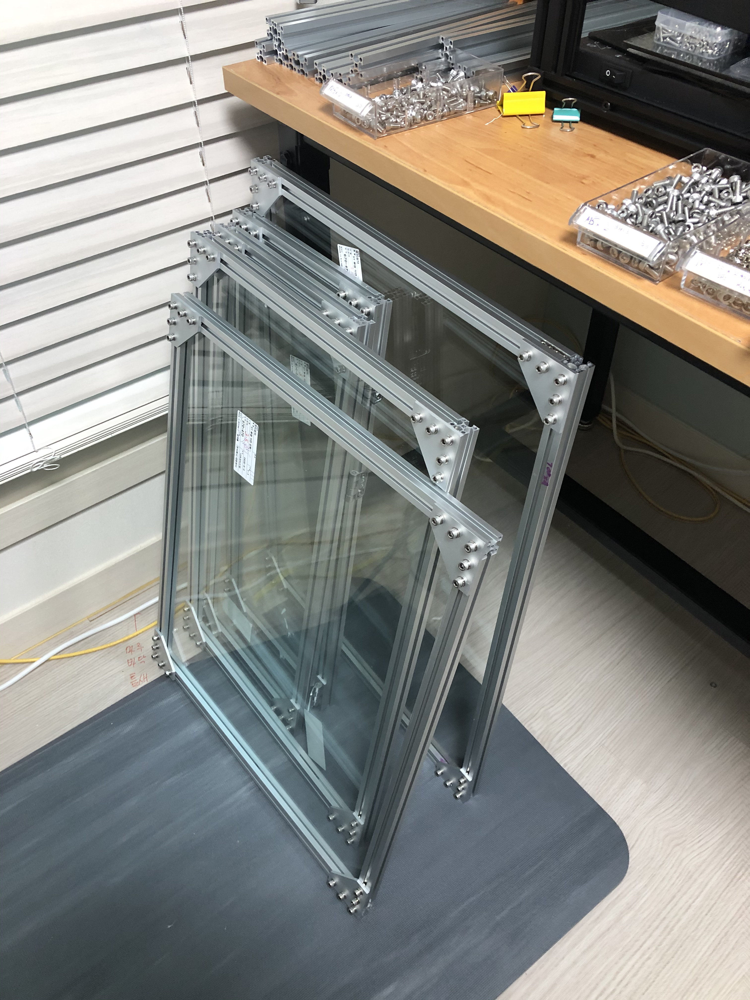
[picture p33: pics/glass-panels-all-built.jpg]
Glass panels assembled


## 2. Make the Oddball Panels

There are several oddball panels, basically partial panels which were
conceptualized to make the top level assembly drawing and parts list a
little less cluttered.  All but the right-side panel are constructed
in-place as the enclosure is assembled.  But the right-side panel is
stand-alone, so build that now.

* FX.R - Right side panel (frame, no glass)

Note: The four corners of this panel will eventually be removed, once it is
put into the final assembly.

The rest of these oddball panels are:

* PS.K - Rear face of enclosure, glass only
* PS.T - Top of enclosure, two rails and four corners only
* PS.B - Botton of enclosure, two rails and four corners only

## 3. Join the Left and Right Sides

Using the four rails which make up the top and bottom sides, join the
left and right sides of the enclosure.  Don't put the top rear rail on
until you install the rear glass panel and gasketing.

#### Cube assembled, time to tap the holes
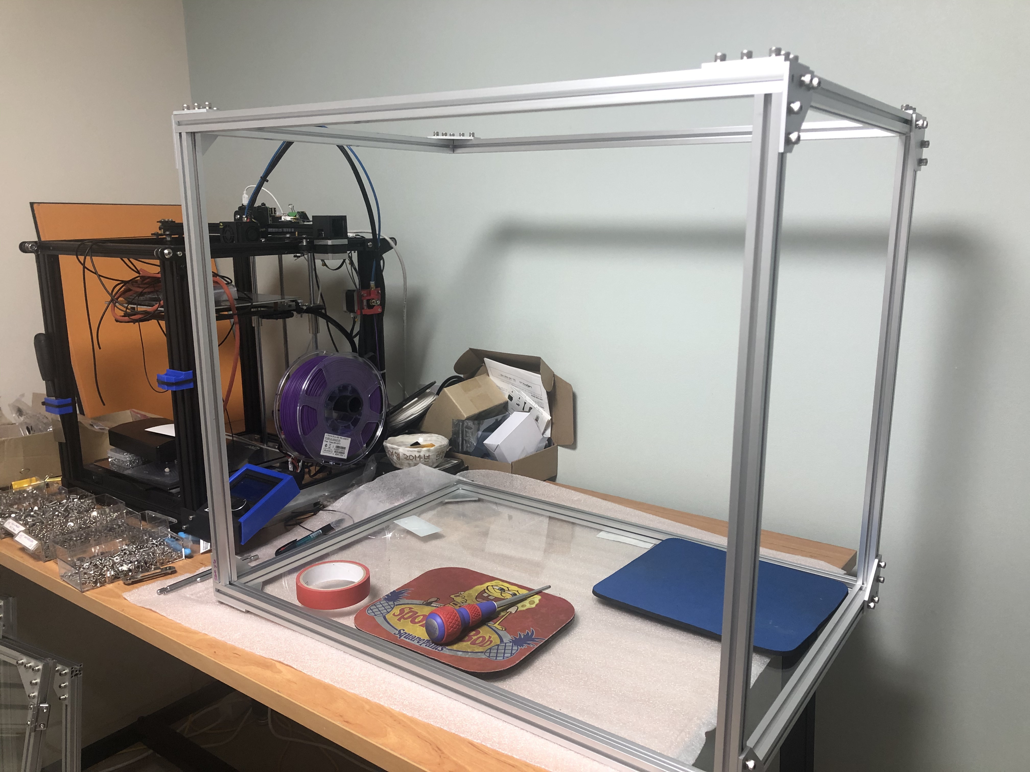
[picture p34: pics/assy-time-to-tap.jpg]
Cube assembled, time to tap the holes


Note, before proceeding to install the doors, thread the center holes of
the four vertical rails with an M4 tap, eight places.  The bottom four
tapped holes can be used to hold feet.  The top four holes are just used
to hold the corner brackets in place.

Once the eight corner plates are installed top and bottom, thus making a
cube, remove the four outward-facing corners on the right side frame.
This allows the right side door to open and close.

#### Completed corner, upper right side
Completed corner

## 4. Install the Doors

Install the two front doors and the side door using hinges and mounting
hardware as indicated in the drawing and parts list.  The top door must
use a hinge with different rail-to-rail spacing, or optionally a spacer
piece of 2020 profile can be screwed along the top rear rail to give
enough offset so the same hinges can be used.  The vertical door hinges
give a 5mm gap between the door and frame.  For the top door, this is
not enough clearance for the corner brackets and socket-head cap screws.
In addition, I wanted extra clearance here for cables.  I went with a
larger hinge, giving a 20 mm gap between the door and frame top.

#### Almost There
Almost There

#### Rear hinge detail
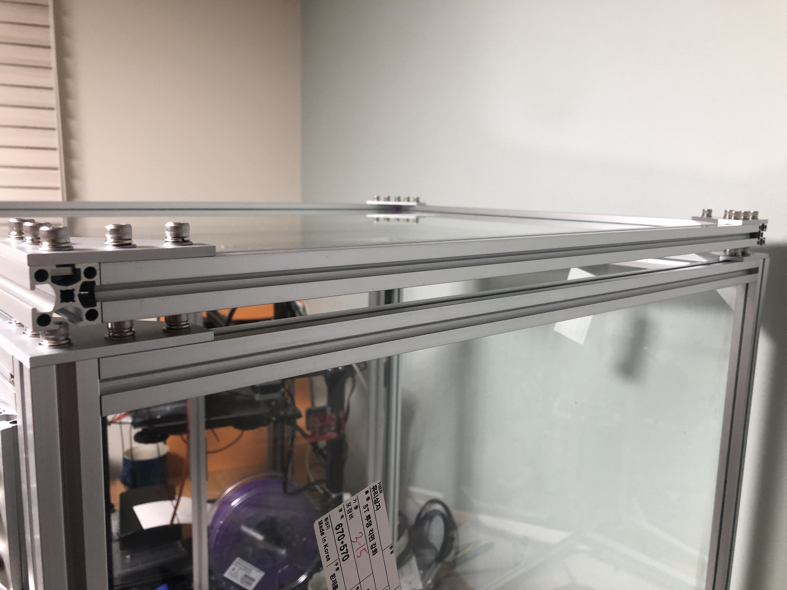
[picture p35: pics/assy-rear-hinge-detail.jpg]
Rear hinge detail


## 5. Accessories

You can accessorize this until the cows come home.  I added a latch to
hold the doors closed.  Some door stops I made from extra corner
brackets and some closed-cell foam.  I put some handles on the top
rails, this thing is heavy and you and a friend need a strong grip to
lift it.  I also put some rubber feet to use a spacers along the front
of the top door to maintain the 20 mm gap spacing.  And finally, I put
rubber feet on the bottom four corners.

#### Front door stop detail
Front door stop detail

#### Door latch detail
Door latch detail

#### Door stop detail
Door stop detail

#### Top door bumpers, left
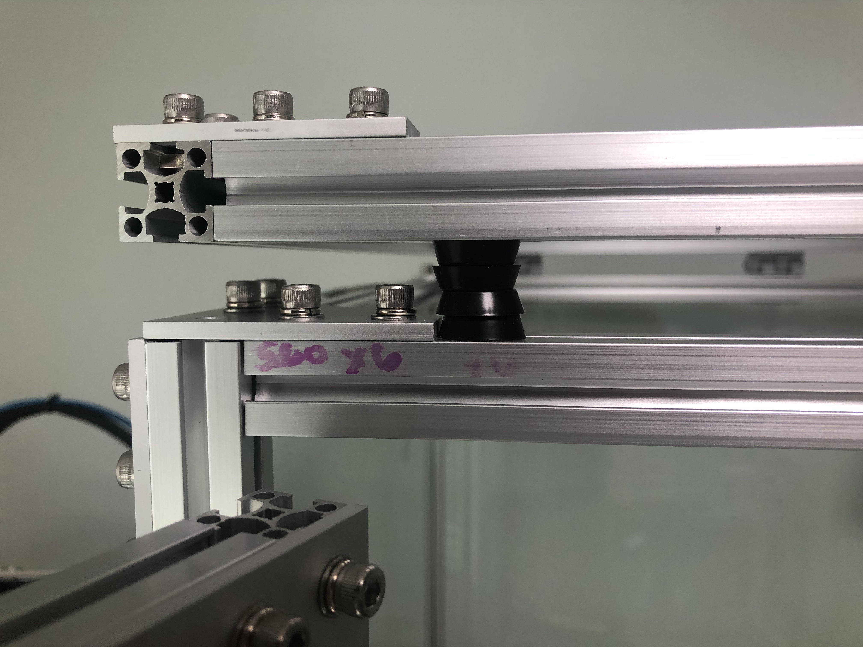
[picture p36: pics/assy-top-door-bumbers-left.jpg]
Top door bumpers, left


#### Top door bumpers, right
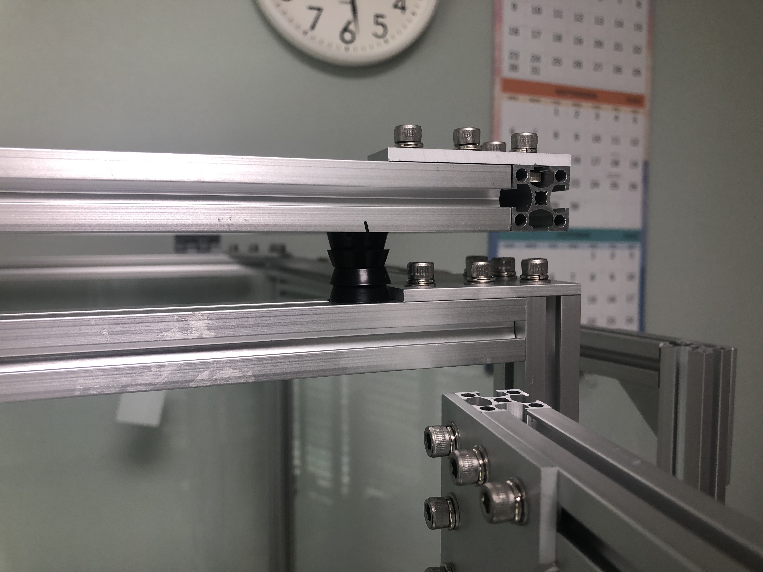
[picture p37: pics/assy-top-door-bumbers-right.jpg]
Top door bumpers, right


## 6. Optional, Future Accessories

In the future, I would like to add a spring or bungee cord to the doors 
to hold them shut.  I'm not crazy about the latches I bought, I would
either replace them or maybe just live with spring action to hold the
doors shut.  One friend has recommended a fire extinguisher ball. And I
still have to mount the various 3D printer accessories, such the
Raspberry Pi 4 Octoprint server, camera, and LED lighting.

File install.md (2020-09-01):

# Simple Installation Notes

Probably incomplete....

The OpenSCAD design relies on three libraries:

* Corner brackets come from user MightyNozzle
  - https://www.thingiverse.com/thing:2503622
  - https://mightynozzle.com

* Flat hinge from NOPSCAD library:
  - https://github.com/nophead/NopSCADlib
  - https://hydraraptor.blogspot.com

* Technical Lettering library:
  - https://github.com/thestumbler/alpha
This was something I wrote a few years ago, before OpenSCAD had
text. I'm not sure it's useful anymore, but I was too lazy to change 
over to the built-in text functions.  This is a TODO item.

The alpha and the bracket code is attached to this repository in the
`uses` directory.  The NOPSCAD library needs to be downloaded and put in
your library path.

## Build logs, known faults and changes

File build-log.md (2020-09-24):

# Calling it Done
_24-Sep-2020_

Belatedly wrapping this up.  There are still small tweaks I'd like to do
here and there, but that will never stop.  Updated drawings, pictures,
and provided assembly instructions.

# Almost Complete
_17-Sep-2020_

Typhoon spared my local town.  Been busy with other things, but finally
got the bulk of the cage assembled.

# Design Details Updated, Video Soon
_07-Sep-2020_
Added some design details to the repo.  Been working on an exploded view
render from OpenSCAD.  Should have it ready tomorrow.  Work and a
nearby typhoon delayed final assembly of the cage another day or two -
that's life.

# Panels a Plenty
_05-Sep-2020_

Built up all the glass panels today.

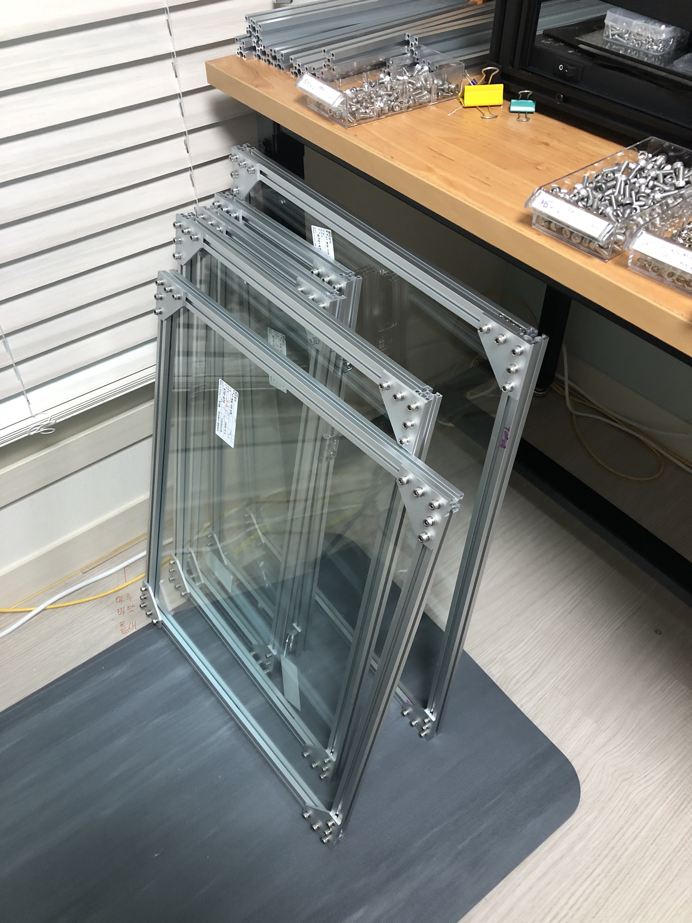
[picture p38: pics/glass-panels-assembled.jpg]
Glass Panels are Assembled


I'll begin the final assembly tomorrow.

Also updated the repository with a final assembly drawing and made a few
BOM corrections.

# A $30 Typo
_01-Sep-2020_

As I started to assemble the first panel tonight, I found yet another
mistake.  I ordered two of the larger panels incorrectly. In this case,
it was an error when I rolled up the various Parts Lists into a
to-purchase BOMs.  It was an extremely unlucky typo - neither of the two
panes were the correct size. 

Ordered:
* 2 ea 640 x 470 mm panes

Needed:
* 1 ea 670 x 470
* 1 ea 670 x 570

I will plow ahead building what I can, new panes on order, should arrive
before Friday if I'm lucky.  Repo updated with revised BOM.

# Project Repository Goes Live
_01-Sep-2020_

Did some cleanup of the files and organization, pushed a project
repository on GitHub.  This repository includes some more photos (I
think I've maxed out the gallery space on Hackaday.io), the OpenSCAD
files, and a 2D CAD drawing ( DWG, DXF, and PDF) of the panel.  The
panels form the basic building blocks of the design.

Yet to do, documentation-wise:

* complete and upload the final assembly drawing
* notes and comments on the design
* explanation of some of the OpenSCAD craziness

As for the enclosure, the remaining six rails of the correct length will
arrive today. I will start assembling everything tonight.  I should have
it assembled and running by the weekend, knock on wood.

# Incoming Inspection
_30-Aug-2020_

Almost all the remaining parts arrived Friday.  A bundle of
cut-to-length 2020 profiles, and the tempered glass panels.  See
gallery.

Despite triple checking my numbers, I mis-ordered on length of profile,
requesting 630 instead of 650mm.  Corrected pieces ordered Saturday,
should get here Monday or Tuesday.

Incoming Inspection, Profiles

I also had one heck of a time with gasket materials to keep the glass
securely in place.  As you will see (when I finally upload my drawings),
I had a careful plan that a pair of 3mm gaskets with circular
cross-sections would be perfect.  Alas, it proved to be a bear to
install them.  First problem was how to install the gaskets.  I
basically had two cylindrical rubber "ropes" that I had to squeeze in
between the glass edges and the insides of the 2020 profile.  This was
proving to be quite awkward.  The second problem was even when I had
only one gasket installed, the force required to bring the frame corners
together was scary. 

Gasket Seating in a Perfect World

In the end, I decided this idea was overkill.  Unlike ordinary gaskets
on windows, whose goal is to prevent leaks, in my application the main
function is to just keep the glass from rattling in the frame.  I pulled
most of the gasket material, and just left a short pieces along each
edge.  Problem solved.

This discussion might be getting ahead of myself, since I still haven't
posted drawings yet, but you can get the idea of the problem from this
sketch above and picture of the test panel in the gallery (that test
panel didn't have any gasket, and taught me that I needed one).

# The Fun Begins
_26-Aug-2020_

I've been curious for some time about 3D printers, but never took the
plunge until the virus hit.  Back in March, a friend of mine pointed out
that he was making miniature people, cars, and buildings for his
HO-gauge model railroad layout using a $300 printer from China.  I knew
the time had come.  His model was the Ender 3, but I splurged and got
the Ender 5 Pro.  

Shortly after receiving my new printer, another friend told me I needed
an enclosure, advice that I kept putting off until I realized he was
right.  After doing a little research, I wasn't really impressed with
any of the off-the-shelf solutions.  Having an enclosure that was not
flammable seemed to be desirable, but many of the popular ones weren't.
Building my own seemed an option, but I imagined complex 3D pieces to
join panes of glass together at the corners began to worry me. And any
"good" enclosure needs doors, panels, mounting points for accessories,
etc.  

Then suddenly, I had an idea ... use the same type of aluminum
extrusions that comprised the 3D printer as frames for a glass
enclosure. and it seemed much more approachable.  This hack page will
force me to document my project, and hopefully nag me to wrap it up
sooner than later.

The main design is locked in.  I was a little worried about a few
educated guesses I made in the design, so I built a small test panel.
Surprisingly, everything went together as expected.  The only tweak was
one I had planned for, that was selecting the type and size of packing
to keep the glass from rattling in the frame.  I have all the hardware
in-hand, and pulled the plug on the extrusions and glass panels
yesterday.

I have a substantial part of the documentation already completed.  This
includes a BOM, with part information and data sheets, and CAD drawings
in DWG/DXF format (assembly drawings) and OpenSCAD for 3D modeling and
exploded view animation.  I'll try to post an update every couple of
days until it's all built and in-service.

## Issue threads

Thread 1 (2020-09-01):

Glass Dimension in Panel Frame Drawing Error

thestumbler, 2020-09-01:
Should be XXX-30 x YYY-30 mm.
Drawing says -10 incorrectly.

Closed 2020-09-02.

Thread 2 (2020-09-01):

Glass panel sizes in BOM roll-up wrong

thestumbler, 2020-09-01:
WAS:

- 2 ea 640 x 470 mm panes

IS:

- 1 ea 670 x 470
- 1 ea 670 x 570

Closed 2020-09-02.

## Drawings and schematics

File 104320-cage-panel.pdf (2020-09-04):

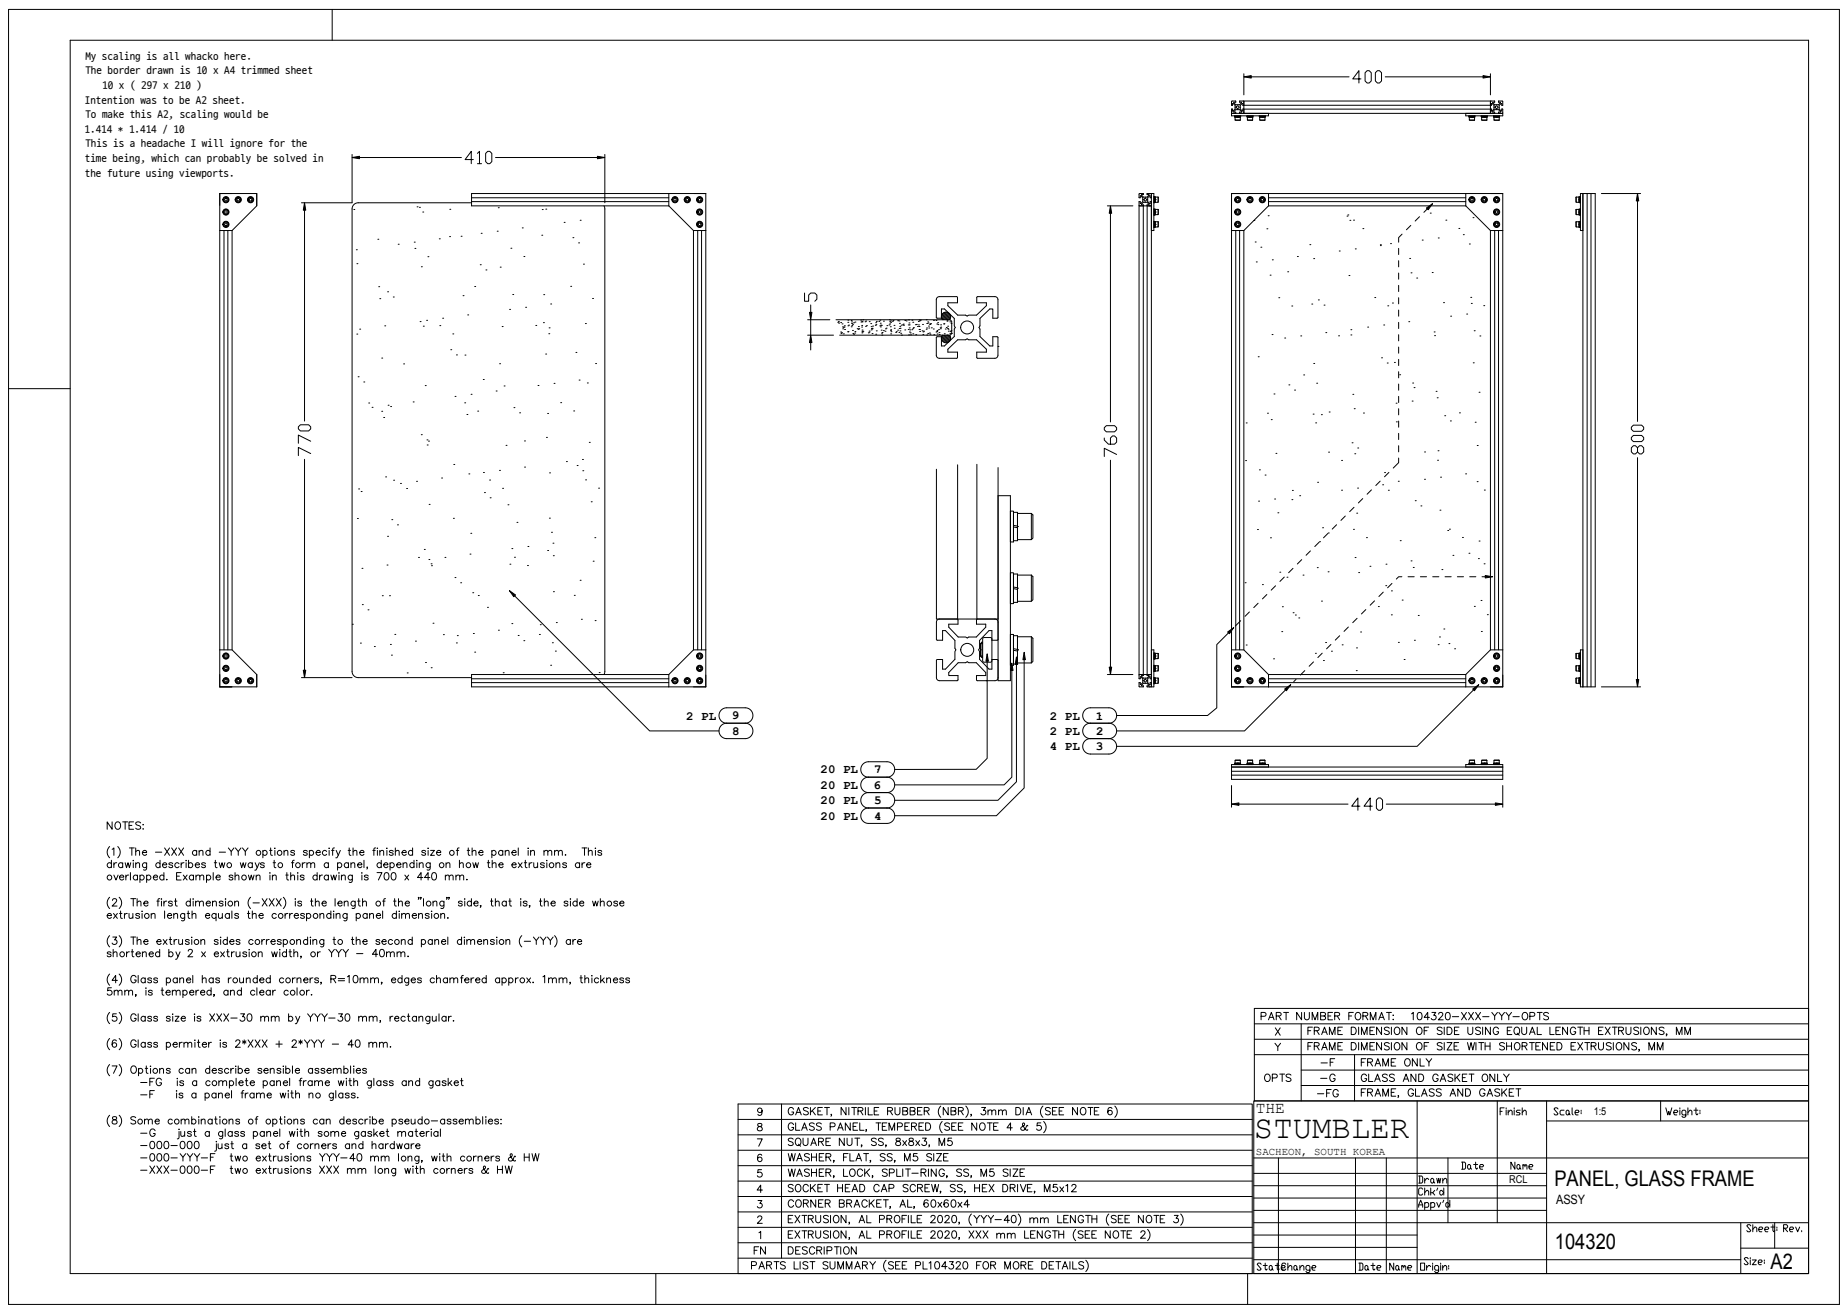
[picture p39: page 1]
SACHEON,; SOUTH KOREA; To make this A2,; scaling would be; time being,; which can probably be solved in

My scaling is all whacko here.

The border drawn is 10 x A4 trimmed sheet

Intention was to be A2 sheet.

This is a headache I will ignore for the

the future using viewports.

PANEL, GLASS FRAME ASSY

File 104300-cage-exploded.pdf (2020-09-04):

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

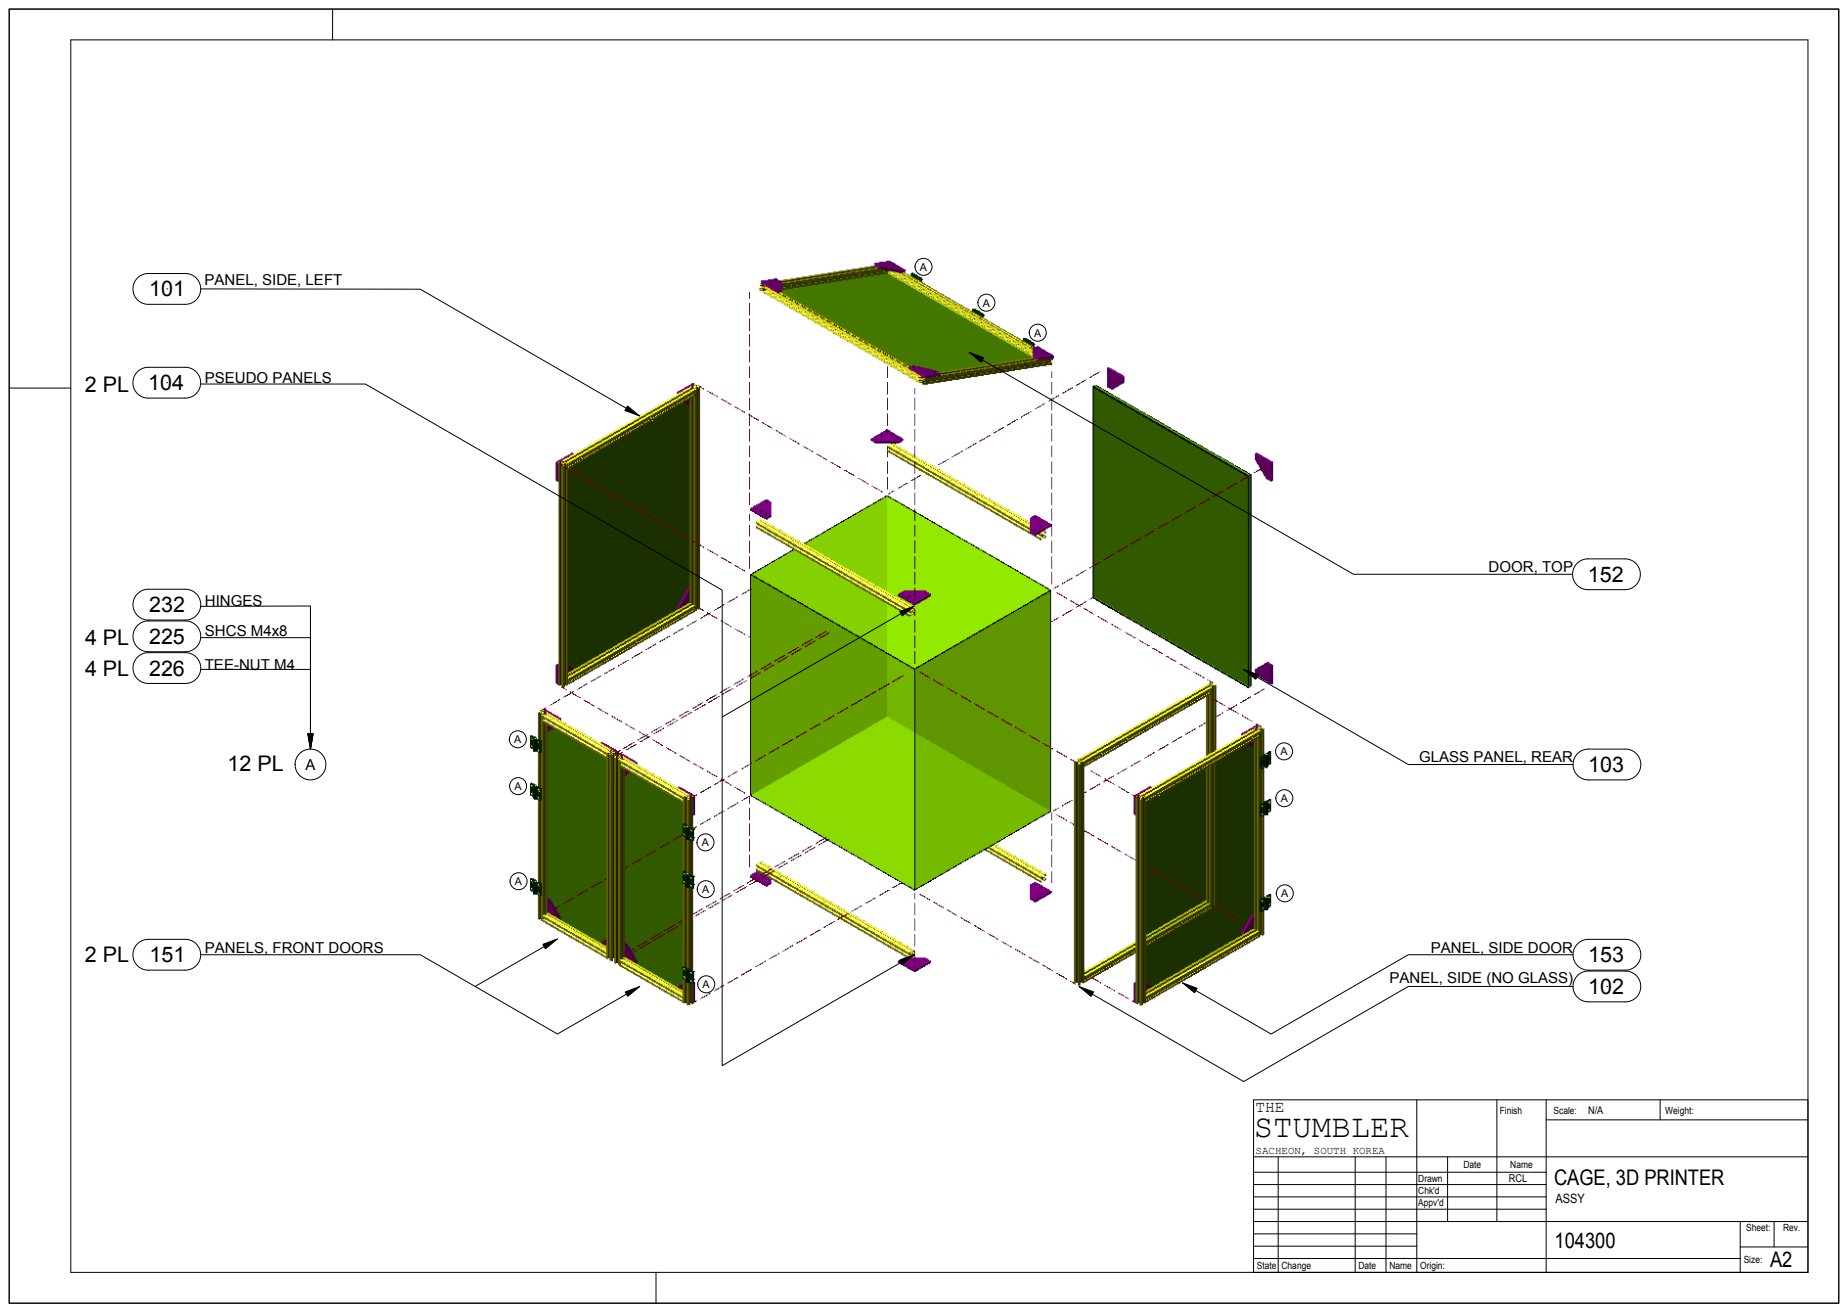
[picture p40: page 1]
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

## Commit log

2020-09-01 Initial release
    [2020.dxf, 2040.dxf, 4020.dxf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]
2020-09-01 Glass panel size corrections left side and back
    [cage-bom.xlsx]
2020-09-02 Corrected issues #1 and #2, began design notes
    [cage-panel.dwg, cage-panel.dxf]
2020-09-04 Added assembly drawing, clarified file names
    [104300-cage-exploded.dwg, 104300-cage-exploded.dxf, 104320-cage-panel.dwg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]
2020-09-05 Corrected quantity of 460mm profile from 2 to 4
    [PL104300-cage-bom.xlsx]
2020-09-05 added picture of assembled panels
2020-09-24 Added assembly pictures and instructions
    [PL104300-cage-bom.xlsx, cage.scad]
